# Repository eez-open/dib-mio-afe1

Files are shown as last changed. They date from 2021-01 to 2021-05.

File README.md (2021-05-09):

The [EEZ DIB](https://github.com/eez-open/modular-psu) 4-channel Hi-voltage/Hi-current AFE for [MIO168](https://github.com/eez-open/dib-mio168) module.

### Feature list
* [ADS131E04](https://www.ti.com/product/ADS131E04) 24-bit 4-channel simultaneous sampling ADC with SPI
* 5½ digit effective resolution
* 2 x Hi-voltage channels featuring software selectable 3 measurement ranges (±2.4 V, ±12 V, ±240 V), and one current range (±240 mA)
* 2 x Hi-current channels featuring software selectable 3 measurement ranes (±24 mA, ±1 A, ±10 A) and 2 voltage ranges (±2.4 V, ±12 V)
* Latching relays for lower continous power consumption
* On-board ±2.5 V low noise LDOs
* Optional Voltage reference (LTC6655-2.5)
* Active clamps on ADC inputs
* 20 x 5 mm fueses on hi-current channels (AIN3 and AIN4)
* Dimensions: 143 x 68.5 mm, 4-layer PCB

### r1B2 prototype

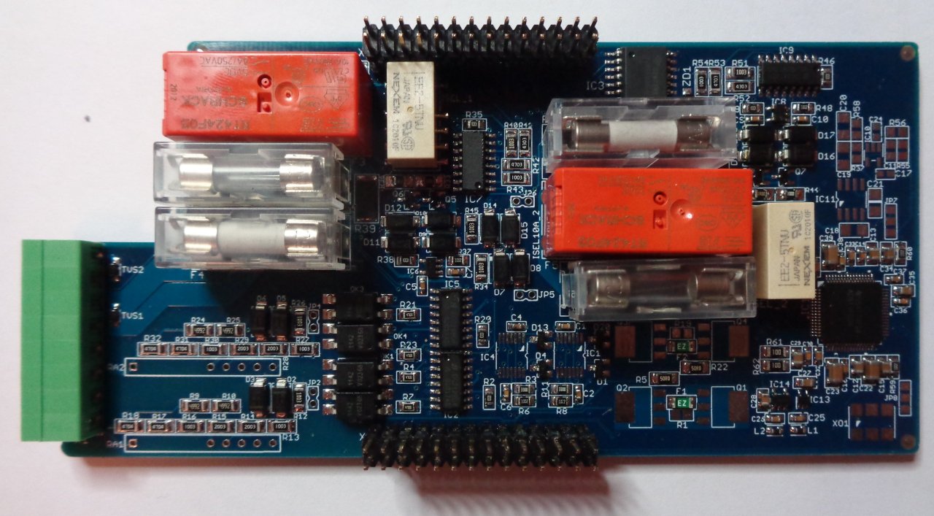
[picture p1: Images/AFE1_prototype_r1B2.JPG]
prototype


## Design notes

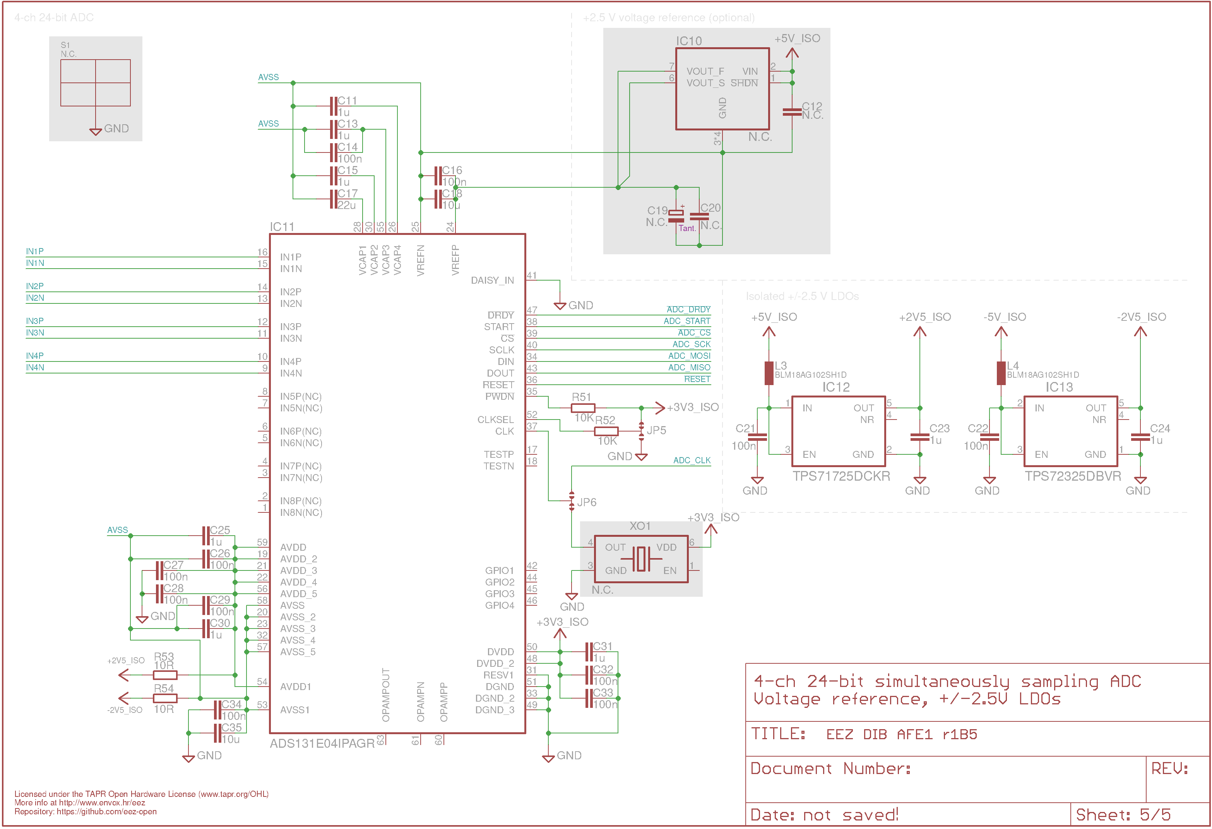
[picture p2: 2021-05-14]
EEZ DIB AFE1 r1B5 Sheet5of5.png

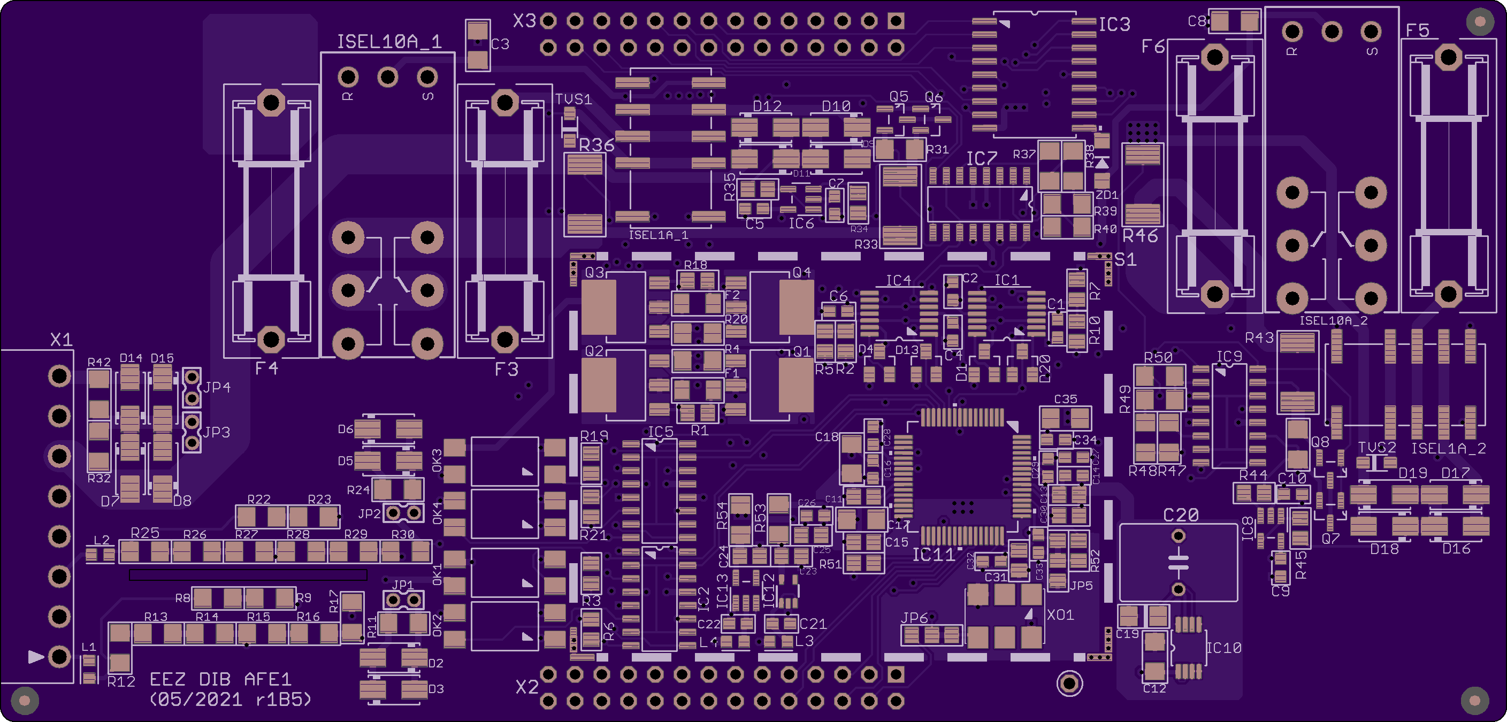
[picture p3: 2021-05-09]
Images/EEZ_DIB_AFE1_PCB_top.png

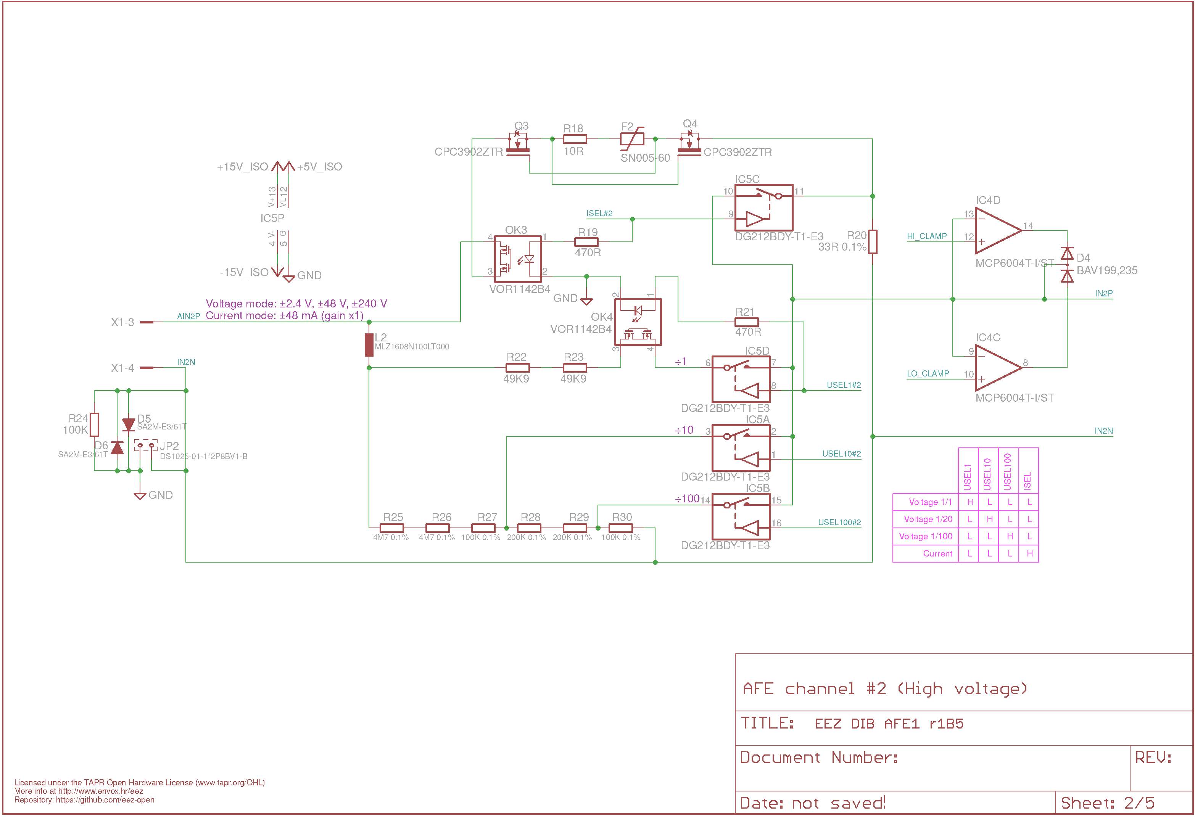
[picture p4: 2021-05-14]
EEZ DIB AFE1 r1B5 Sheet2of5.png

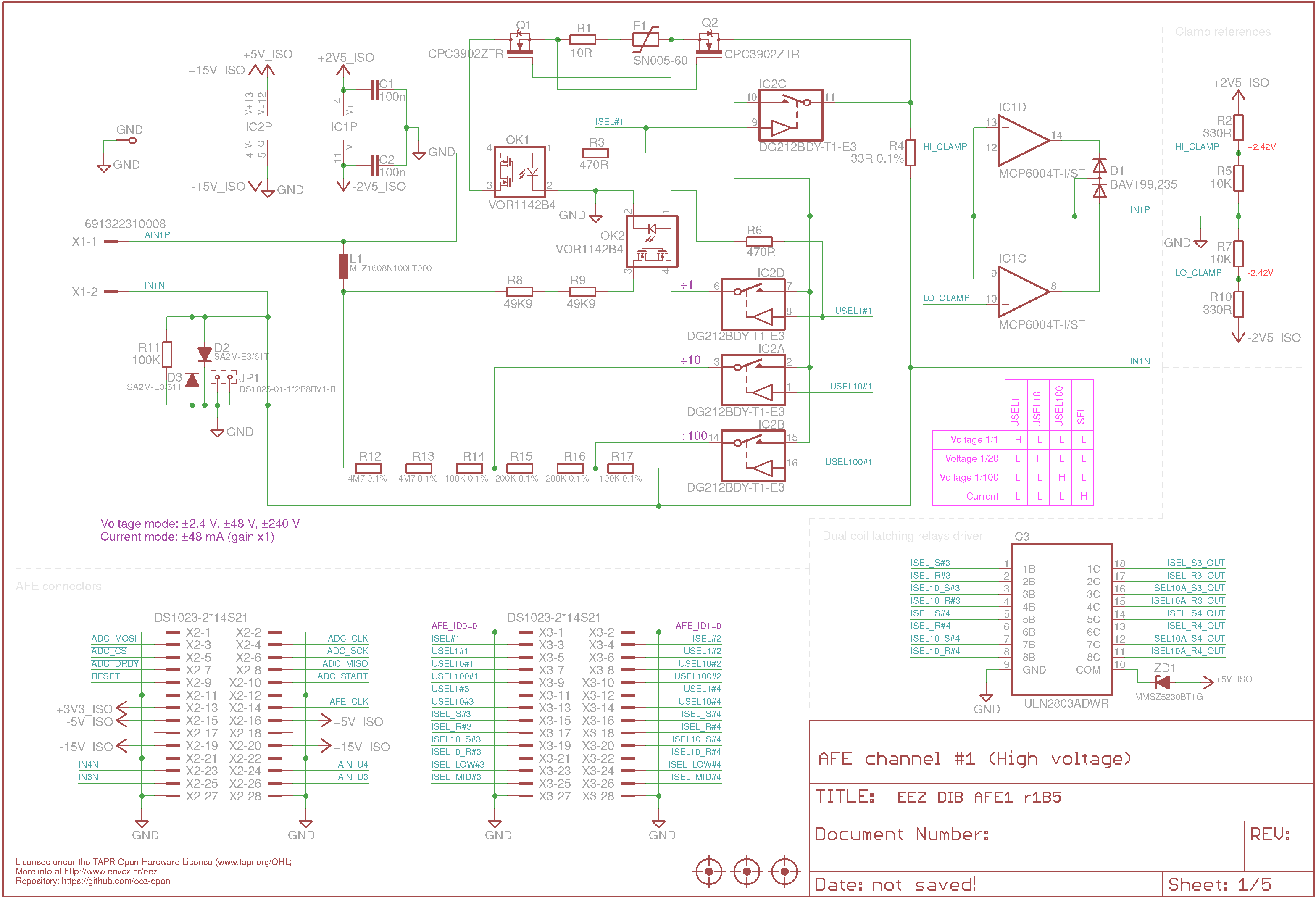
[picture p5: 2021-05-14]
EEZ DIB AFE1 r1B5 Sheet1of5.png

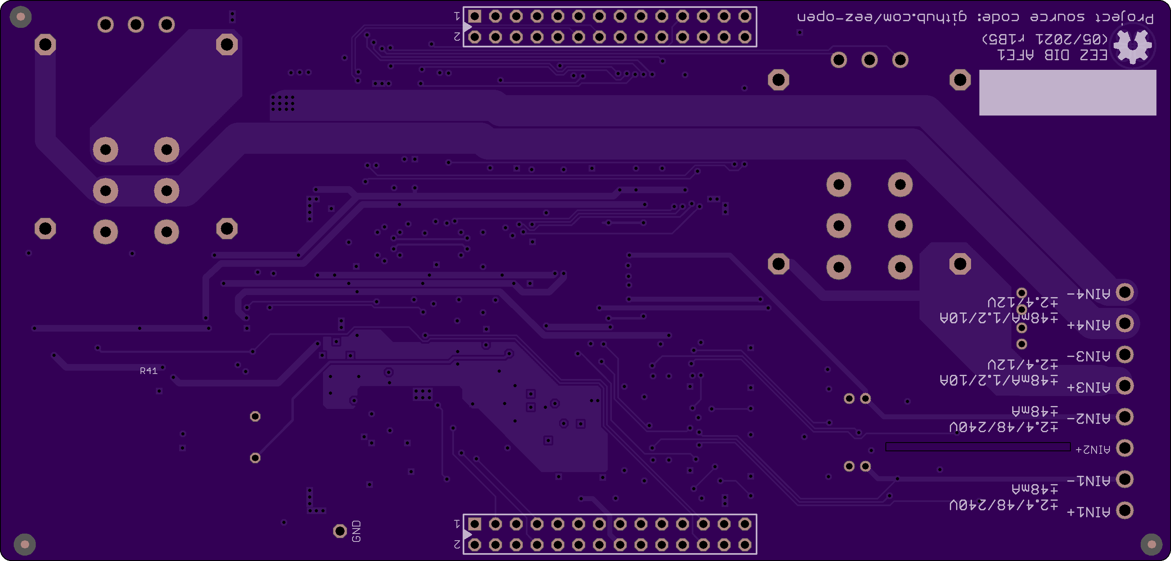
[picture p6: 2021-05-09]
Images/EEZ_DIB_AFE1_PCB_bottom.png

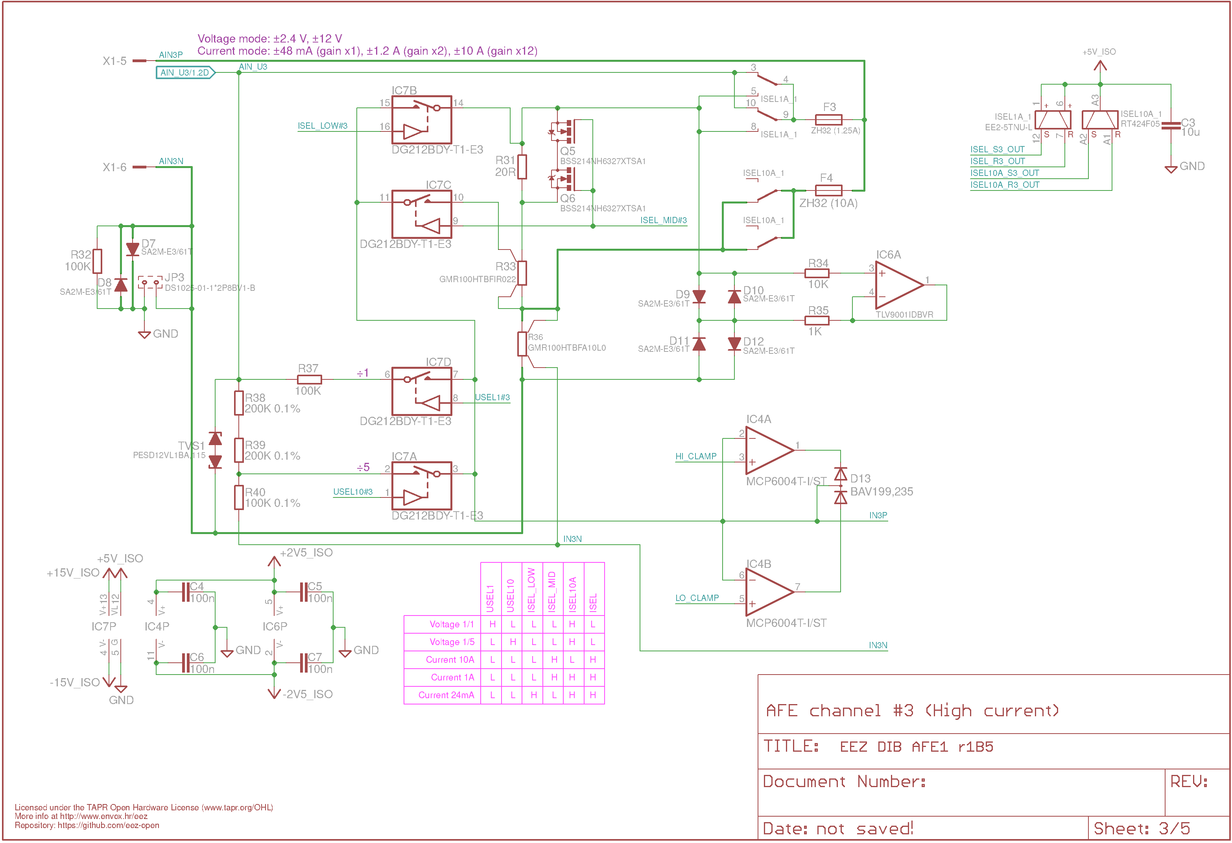
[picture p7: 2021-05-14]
EEZ DIB AFE1 r1B5 Sheet3of5.png

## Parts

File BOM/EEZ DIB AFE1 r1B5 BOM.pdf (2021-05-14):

EEZ DIB AFE1 BOM (r1B5, 2021-05-14)
Project source code at https://github.com/eez-open/modular-psu
Farnell / Element14 # Unit price Qty Part name Package Reference designator Code Part Number MOQ € | Digi-Key Unit price Part Number MOQ € | Mouser Unit price Part Number MOQ €
| | 80-C0603C104M4R
C11, C13, C15, C23, C24, C25, C30, C31 | | 963-TMK212B7105K G-T
| | 603-CC121KKX7R8B B226
MC0603B102K250 CT | | 80-C0603C102J5RA C
| | 810-CGA4J1X7S1C1 06KA
1 | 19 100n | 0603 | 2522597 | 0,073 10 | 490-4774-1-ND | 0,090 100 | 0,085 100
2 | 8 1u | 0805 | 2495193 | 885012207078 | 0,139 | 5 | 1276-1066-1-ND | 0,070 | 10 | 0,050 10
3 | 1 22u | 1206 | C17 | 2320935 | 1,490 | 1 | 1276-3373-1-ND | 0,369 | 10 | 0,777 10
4 | 2 1n | 0603 | C2, C10 | 2627426 | 0,009 10 | 1276-1018-1-ND | 0,026 | 10 | 0,021 10
5 | 4 10u | 1206 | C3, C8, C18, C35 | 3013485 | 0,262 10 | 1276-2872-1-ND | 0,207 | 10 | 0,144 | 1
6 | 4 BAV199,235 | SOT-23 | D1, D4, D13, D20 | 2319137 | BAV199,215 | 0,185 | 5 | 1727-6382-1-ND | 0,145 | 10 | 771-BAV199235 | 0,146 10
7 | 16 SA2M-E3/61T | SMA | 2335163 | SA2M-E3/61T | 0,261 10 | 0,223 | 10 | 78-CSA2M-E3/H | 0,202 10
8 | 1 SN005-60 | 1206 | F1, F2 | 3103210 | 1206L005/60WR | 0,771 | 1 | F8129CT-ND | 0,460 | 1 | | 0,440 | 1
9 | 4 ZH32 | | F3, F4, F5, F6 | - | | | | - | | | -
10 | 2 MCP6004T-I/ST | TSSOP-14 | IC1, IC4 | - | | | | - | | | | 0,373 | 1
11 | 1 ADS131E04IPAGR | TQFP-64 | IC11 | 3123346 | ADS131E04IPAG | 13,450 | 1 | 296-34885-1-ND | 7,560 | 1 | | 8,430 | 1
12 | 1 TPS71725DCKR | SC70-5 | IC12 | 2348004 | TPS71725DCKR . | 0,982 | 1 | 296-21525-1-ND | 0,890 | 1 | | 0,889 | 1
13 | 1 TPS72325DBVR | SOT-23-5 | IC13 | 3007843 | TPS72325DBVR | 2,690 | 1 | 296-39479-1-ND | 2,300 | 1 | | 2,310 | 1
14 | 4 DG212BDY-T1-E3 | SOIC-16 | IC2, IC5, IC7, IC9 | 1469429 | DG212BDY-T1-E3 | 1,820 | 1 | | 1,550 | 1 | | 1,470 | 1
15 | 1 ULN2803ADWR | SOIC-18 | IC3 | 3125103 | ULN2803ADWR | 1,120 | 5 | 296-15777-1-ND | 1,090 | 1 | | 1,090 | 1
16 | 2 | SOT-23-5 | IC6, IC8 | 4974992 | MCP6001T-I/OT | 0,219 | 1 | | 0,200 | 1 | | 0,203 | 1
17 | 2 RT424F05 | | ISEL10A_1, ISEL10A_2 | 3406968 | RT424F05 | 6,450 | 1 | PB2024-ND | 6,370 | 1 | 655-5-1393243-2 | 6,380 | 1
18 | 2 EE2-5TNU-L | | ISEL1A_1, ISEL1A_2 | 2360813 | EE2-5TNU-L | 1,900 | 1 | 399-11021-1-ND | 2,110 | 1 | 80-EE2-5TNU-L | 2,120 | 1
19 | 4 DS1025-01-1*2P8BV1-B | | JP1, JP2, JP3, JP4 | - | | | | - | | | -
20 | 2 MLZ1608N100LT000 | 0603 | L1, L2 | 2564062 | 0,167 10 | 445-6755-1-ND | 0,111 | 10 | 0,086 10
21 | 2 BLM18AG102SH1D | 0603 | L3, L4 | 3471092 | 0,032 10 | 490-7809-1-ND | 0,070 | 10 | 0,051 10
22 | 4 VOR1142B4 | SMD DIP-4 | OK1, OK2, OK3, OK4 | 2889672 | VOR1142B4 | 1,660 | 1 | VOR1142B4-ND | 1,420 | 1 | 78-VOR1142B4 | 1,420 | 1

C1, C2, C4, C5, C6, C7, C9, C10, C14, C16, C21, C22,
C26, C27, C28, C29, C32,
C33, C34

C0603C104K4RAC
7081

MC1210X226K250
CT

CL21B106KOQNN
NE

D2, D3, D5, D6, D7, D8, D9, D10, D11, D12, D14, D15,
D16, D17, D18, D19

CSA2M-E3/ IGICT-ND

| 576-1206L005/60WR

THT; 20x5mm fuse holder
| | 579-MCP6004T-I/ST
| | 595-ADS131E04IPAG R
| | 595-TPS71725DCKR
| | 595-TPS72325DBVR
| DG212BDY-T1-E3CT-ND | 781-DG212BDY-T1-E3
| | 595-ULN2803ADWR
MCP6001T-I/OT or TLV9001IDBVR | MCP6001T-I/ OTCT-ND | 579-MCP6001T-E/OT

THT; DPDT Latching relay
DPDT Latching relay, Gull
Wing Lead
THT; 2- pin header, 2 mm
MLZ1608N100LT0 00 | 810-MLZ1608N100LT 000
| 81-BLM18AG102SH 1D

BLM18AG102SH1
D

# Qty Part name | RS Components | TME | Price calculation for 1 set

Unit price Code Part Number MOQ € | Unit price Code / Part Number MOQ € | THT SMD | | Line Cost €

1 19 100n

2 8 1u

3 1 22u

4 2 1n

5 4 10u

6 4 BAV199,235
7 16 SA2M-E3/61T

8 1 SN005-60

9 4 ZH32
10 2 MCP6004T-I/ST

11 1 ADS131E04IPAGR

12 1 TPS71725DCKR

13 1 TPS72325DBVR

14 4 DG212BDY-T1-E3

15 1 ULN2803ADWR

16 2

17 2 RT424F05
18 2 EE2-5TNU-L

19 4 DS1025-01-1*2P8BV1-B
20 2 MLZ1608N100LT000

21 2 BLM18AG102SH1D

22 4 VOR1142B4

MCP6001T-I/OT or
TLV9001IDBVR
264-4630 | 0,035 25 | CL10B104KA8NNNC | 0,098 100 | 19 | RS | 0,035 € 19 | 0,665
378-665 | 0,038 25 | 0,014 100 | 8 | TME | 0,014 € | 8 | 0,116
766-1182 | 0,343 10 | CL32A226KAJNNNE | 0,158 10 | 1 | TME | 0,158 € | 1 | 0,158
135-6565 | 0,014 100 | 0,010 100 | 2 | Farnell | 0,009 € | 2 | 0,018
184-3969 | 0,233 50 | CL21A106KOQNNNG | 0,034 100 | 4 | TME | 0,034 € | 4 | 0,137
751-3437 BAV199DW-7-F | 0,232 25 | BAV199.215 | 0,035 20 | 4 | TME | 0,035 € | 4 | 0,140
812-9275 SA2M-E3/5AT | 0,116 100 | SA2M-E3/61T | 0,050 50 | 16 | TME | 0,050 € 16 | 0,794
- | SN005-60 | 0,075 10 | 1 | TME | 0,075 € | 1 | 0,075
- | | | ZH32 | 0,228 | 5 | 4 | TME | 0,228 € | 4 | 0,912
- | | | - | | | 2 | Mouser | 0,373 € | 2 | 0,746
817-5705 | 6,050 | 1 | - | | | 1 | RS | 6,050 € | 1 | 6,050
- | | | - | | | 1 | Mouser | 0,889 € | 1 | 0,889
- | | | - | | | 1 | Digikey | 2,300 € | 1 | 2,300
710-4780 | 1,630 | 5 | - | | | 4 | Mouser | 1,470 € | 4 | 5,880
646-6311 ULN2803ADW | 1,336 | 1 | ULN2803ADWR | 0,866 | 1 | 1 | TME | 0,866 € | 1 | 0,866
698-9041 MCP6001T-I/OT | 0,230 | 1 | MCP6001T-I/OT | 0,254 | 3 | 2 | Digikey | 0,203 € | 2 | 0,406
164-7553 RT424F05 | 6,485 | 1 | 5-1393243-2 | 2,500 | 2 | 2 | TME | 2,500 € | 2 | 5,000
870-5517 EE2-5TNU-L | 1,987 | 1 | - | | | 2 | Farnell | 1,900 € | 2 | 3,800
- | ZL303-02P | 0,013 50 | 4 | TME | 0,013 € | 4 | 0,051
- | | | - | | | 2 | Mouser | 0,086 € | 2 | 0,172
839-0803 | 0,025 100 | BLM18AG102SH1D | 0,016 50 | 2 | TME | 0,016 € | 2 | 0,031
180-7266 VOR1142B4 | 1,416 | 5 | - | | | 4 | RS | 1,416 € | 4 | 5,664

Best
Supplier

Lowest
unit price
€

Order
Qty

C0603C104K4R
ACTU

08052R104K8B
B

VJ0805Y105KXXTW1
BC

CL32A226KAJN
NNE

06031C102KAZ
2A

VJ0603Y102KXACW1
BC

EMK212BB7106
MG-T

ADS131E04IPA
G

DG212BDY-T1-
E3

BLM18AG102S
H1D

# Qty Part name Package Reference designator Code Part Number MOQ € | Part Number Unit price MOQ € | Part Number Unit price MOQ Unit price €

| | 849-CPC3902ZTR
BSS214NH6327XT SA1 | BSS214NH6327 XTSA1CT-ND | 726-BSS214NH6327
| 2019-RK73H2ATTD10 R0FCT-ND | 652-CR0805FX-10R0ELF
R11, R24, R32, R37, R42, MCWR08X1003FT R47 L | RMCF0805FT10 0KCT-ND | 71-CRCW0805100K FKEAC
| | 754-RG3216P-4704B-T1
R14, R17, R27, R30, R40, R50 | RG32P100KBCT -ND | 754-RG3216P-1003-BT5
| RG32P200KBCT -ND | 754-RG3216P-2003-BT5
MCWR08X3300FT L | | 279-CRGCQ0805F33 0R
| 311-470CRCT-ND | 71-CRCW0805470R FKEB
1206, low TCR (max. ±25ppm/°C) | | 652-CRT1206BY20R 0ELF
| | 755-GMR100HTBFIR 022
| RC0805FR-071KL | 603-RC0805FR-071KL
| | 755-GMR100HTBFA1 0L0
1206, low TCR (max. ±25ppm/°C) | 13-RT1206BRD0733 RLCT-ND | 603-RT1206BRD0733 RL
| ND | 603-RC0805FR-0710KL
CR1206-FX-4992ELF | RNCP1206FTD4 9K9CT-ND | 791-MR12X4992FTL
| | 771-PESD12VL1BA-T/R
THT, 8-pin 3.81mm terminal block header, male pins | | 710-691322310008
23 | 4 CPC3902ZTR | SOT-223 | Q1, Q2, Q3, Q4 | - | CLA4156-1-ND | 0,570 | 1 | 0,576 | 1
24 | 4 BSS214NH6327XTSA1 SOT-23 | Q5, Q6, Q7, Q8 | 2480650 | 0,408 | 5 | 0,255 | 10 | 0,224 10
25 | 4 10R | 0805 | R1, R18, R53, R54 | 2447556 | 0,009 10 | 0,029 | 10 | 0,012 10
26 | 6 100K | 1206 | 2447551 | 0,010 10 | 0,024 | 10 | 0,040 10
27 | 4 4M7 0.1% | 1206 | R12, R13, R25, R26 | - | 408-2037-1-ND | 0,413 | 10 | 0,356 10
28 | 6 100K 0.1% | 1206 | 1717738 | ERA8AEB101V | 0,482 10 | 0,346 | 10 | 0,226 10
29 | 8 200K 0.1% | 1206 | 1841801 | ERA8AEB204V | 0,468 10 | 0,355 | 10 | 0,226 10
30 | 2 330R | 0805 | R2, R10 | 2447638 | 0,007 10 | A106061CT-ND | 0,038 | 10 | 0,036 10
31 | 4 470R | 0805 | R3, R6, R19, R21 | 1099798 | WCR0805-470RFI | 0,019 10 | 0,039 | 10 | 0,041 10
32 | 2 20R | R31, R41 | - | 311-2930-1-ND | 0,202 | 10 | 0,257 10
33 | 2 GMR100HTBFIR022 | R33, R43 | - | 511-1688-1-ND | 1,090 | 10 | 1,250 | 1
34 | 2 1K | 0805 | R35, R45 | 1099800 | WCR0805-1K0FI | 0,019 10 | 0,039 | 10 | 0,015 10
35 | 2 GMR100HTBFA10L0 | R36, R46 | 2808330 | 1,130 | 5 | 511-1686-1-ND | 1,350 | 1 | 1,080 | 1
36 | 2 33R 0.1% | R4, R20 | - | 0,394 | 10 | 0,266 10
37 | 6 10K | 0805 | R5, R7, R34, R44, R51, R52 9237755 | 0,022 10 | 0,039 | 10 | 0,014 10
38 | 4 49K9 | 1206 | R8, R9, R22, R23 | 2908458 | 0,040 10 | 0,068 | 10 | 0,013 10
39 | 2 PESD12VL1BA,115 | SOD-323 | TVS1, TVS2 | 8737363 | 0,365 | 5 | 1727-3808-1-ND | 0,320 | 10 | 0,296 10
40 | 1 691322310008 | X1 | - | 732-2093-ND | 1,390 | 1 | 1,400 | 1
41 | 2 P125-2214A0BS230A1 | X2, X3 | - | - | -

MCWR08X10R0FT
L

R15, R16, R28, R29, R38,
R39, R48, R49

2512, low TCR (max.
±25ppm/°C)

2512, low TCR (max.
±25ppm/°C)

GMR100HTBFA10
L0
RC0805FR-0710KL | 311-10.0KCRCT-

PESD12VL1BA,11
5

THT; 28-pin 0.1” board-toboard (Producer: DONG
GUAN YLIES PRECISE
CONNECTOR CO.,LTD)

# Qty Part name

23 4 CPC3902ZTR

24 4 BSS214NH6327XTSA1

25 4 10R

26 6 100K

27 4 4M7 0.1%

28 6 100K 0.1%

29 8 200K 0.1%

30 2 330R

31 4 470R

32 2 20R

33 2 GMR100HTBFIR022

34 2 1K

35 2 GMR100HTBFA10L0

36 2 33R 0.1%

37 6 10K

38 4 49K9

39 2 PESD12VL1BA,115

40 1 691322310008

41 2 P125-2214A0BS230A1

Code Part Number MOQ € | Code / Part Number Unit price MOQ € | THT SMD | Line Cost € Unit price

Best
Supplier

Lowest
unit price
€

Order
Qty
- | CPC3902ZTR | 0,310 | 5 | 4 | TME | 0,310 € | 4 | 1,240
827-0058 | 0,107 100 | 0,070 10 | 4 | TME | 0,070 € | 4 | 0,280
740-8987 | 0,065 50 | 0805S8J0111T5E | 0,013 100 | 4 | Farnell | 0,009 € | 4 | 0,034
223-0691 CRG0805F100K | 0,028 50 | 0805S8F1003T5E | 0,015 100 | 6 | Farnell | 0,010 € | 6 | 0,058
- | - | 4 | Mouser | 0,356 € | 4 | 1,424
669-6626 ERA8AEB104V | 0,608 | 5 | AR06BTCV1003 | 0,127 10 | 6 | TME | 0,127 € | 6 | 0,759
828-0715 ERA8AEB204V | 0,608 | 5 | AR06BTCV2003 | 0,127 10 | 8 | TME | 0,127 € | 8 | 1,013
223-0354 CRG0805F330R | 0,040 50 | 0805S8F3300T5E | 0,014 100 | 2 | Farnell | 0,007 € | 2 | 0,014
223-0376 CRG0805F470R | 0,021 50 | RC0805FR-07470R | 0,022 100 | 4 | Farnell | 0,019 € | 4 | 0,076
- | - | 2 | Digikey | 0,202 € | 2 | 0,404
- | - | 2 | Digikey | 1,090 € | 2 | 2,180
223-0427 CRG0805F1K0 | 0,017 50 | RC0805FR-071K | 0,022 100 | 2 | Mouser | 0,015 € | 2 | 0,030
- | - | 2 | Mouser | 1,080 € | 2 | 2,160
- | ARG06DTC0330 | 0,029 10 | 2 | TME | 0,029 € | 2 | 0,058
125-1189 CRG0805F10K | 0,002 100 | RC0805FR-0710K | 0,022 100 | 6 | RS | 0,002 € | 6 | 0,012
679-2174 | 0,039 50 | RC1206FR-0749K9 | 0,029 100 | 4 | Mouser | 0,013 € | 4 | 0,052
508-024 | 0,294 20 | PESD12VL1BA.115 | 0,126 | 5 | 2 | TME | 0,126 € | 2 | 0,252
824-6661 691322310008 | 1,470 | 1 | 15EDGRC3.81-08P | 0,662 | 1 | 1 | TME | 0,662 € | 1 | 0,662
- | - | 2 | -

BSS214NH6327
XTSA1

BSS214NH6327XTSA
1
CR0805-FX-10R0ELF

CRCW120649K
9FKEA
PESD12VL1BA,
115

# Qty Part name Package Reference designator Code Part Number MOQ € | Part Number Unit price MOQ € | Part Number Unit price MOQ Unit price €

| MMSZ5230BT1G OSCT-ND | 863-MMSZ5230BT1G
42 | 1 MMSZ5230BT1G | SOD-123 | ZD1 | 1431272 | MMSZ5230BT1G | 0,177 10 | 0,148 | 10 | 0,170 10

Not installed
1 N.C. | 1206 | C12
4 N.C. | 1206 | C19
1 N.C. | THT | C20
1 N.C. | IC10
5 N.C. | R-EU_R0805 | R4, R9, R40, R41, R42
1 N.C. | S1
1 N.C. | XO1

Related parts and accessories
2 ZKSS-10A
2 ZKSS-1.25A
4 JUMPER-2.0/R | JP1, JP2, JP3, JP4 | - | - | -
1 691304100008 | - | 277-12329-ND | 7,410 | 1 | 651-1748037 | 7,440 | 1

Custom made components
1 | JLCPCB.com | -

All prices are net prices (without VAT)

All resistors are 1% 0805 and all capacitors are X7R 0805 if not otherwise specified.
For small quantities, consider ordering specialized chips at store.ti.com for better prices and availability.

8-pin 3.81mm push-in
connector

PCB 4-layer 141.5 x 68.5
mm

Please note that BOM does not contain ordering number for parts on reels or that which includes re-reeling fee. Take also into account that total cost is higher because min. quantity (MOQ) for many parts is larger then what is needed for single unit.

# Qty Part name

42 1 MMSZ5230BT1G

Not installed
1 N.C.
4 N.C.
1 N.C.
1 N.C.
5 N.C.
1 N.C.
1 N.C.

Related parts and accessories 2 ZKSS-10A
2 ZKSS-1.25A
4 JUMPER-2.0/R
1 691304100008

Custom made components
1 PCB 4-layer 141.5 x 68.5 mm
Code Part Number MOQ € | Code / Part Number Unit price MOQ € | THT SMD | Line Cost € Unit price
| MMSZ5230BT1 G

Best
Supplier

Lowest
unit price
€

Order
Qty
545-3033 | 0,173 20 | MMSZ5230BT1G | 0,033 25 | 1 | TME | 0,033 € | 1 | 0,033
13 | 108 | 45,61 €
ZKSS-10A | 0,459 10 | TME | 0,459 € | 2 | 0,918
ZKSS-1.25A | 0,312 10 | TME | 0,312 € | 2 | 0,624
- | JUMPER-2.0/R | 0,044 20 | TME | 0,044 € | 4 | 0,175
185-4361 691304100008 | 8,900 | 1 | Digikey | 7,410 € | 1 | 7,410

9,13 €

JLCPCB | 8,796 € | 1 | 8,796
| | | 8,80 €
| | Total | 63,53 €

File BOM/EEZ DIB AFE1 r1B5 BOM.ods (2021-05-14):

 |  |  |  |  | Farnell / Element14 |  |  |  | Digi-Key |  |  | Mouser |  |  | RS Components |  |  |  | TME |  |  |  |  | Price calculation for 1 set
# | Qty | Part name | Package | Reference designator | Code | Part Number | Unit price € | MOQ | Part Number | Unit price € | MOQ | Part Number | Unit price € | MOQ | Code | Part Number | Unit price € | MOQ | Code / Part Number | Unit price € | MOQ | THT | SMD | Best Supplier | Lowest unit price € | Order Qty | Line Cost €
1 | 19 | 100n | 0603 | C1, C2, C4, C5, C6, C7, C9, C10, C14, C16, C21, C22, C26, C27, C28, C29, C32, C33, C34 | 2522597 | C0603C104K4RAC7081 | 0,073 | 10 | 490-4774-1-ND | 0,090 | 100 | 80-C0603C104M4R | 0,085 | 100 | 264-4630 | C0603C104K4RACTU | 0,035 | 25 | CL10B104KA8NNNC | 0,098 | 100 |  | 19 | RS | 0,035 € | 19 | 0,665
2 | 8 | 1u | 0805 | C11, C13, C15, C23, C24, C25, C30, C31 | 2495193 | 885012207078 | 0,139 | 5 | 1276-1066-1-ND | 0,070 | 10 | 963-TMK212B7105KG-T | 0,050 | 10 | 378-665 | 08052R104K8BB | 0,038 | 25 | VJ0805Y105KXXTW1BC | 0,014 | 100 |  | 8 | TME | 0,014 € | 8 | 0,116
3 | 1 | 22u | 1206 | C17 | 2320935 | MC1210X226K250CT | 1,490 | 1 | 1276-3373-1-ND | 0,369 | 10 | 603-CC121KKX7R8BB226 | 0,777 | 10 | 766-1182 | CL32A226KAJNNNE | 0,343 | 10 | CL32A226KAJNNNE | 0,158 | 10 |  | 1 | TME | 0,158 € | 1 | 0,158
4 | 2 | 1n | 0603 | C2, C10 | 2627426 | MC0603B102K250CT | 0,009 | 10 | 1276-1018-1-ND | 0,026 | 10 | 80-C0603C102J5RAC | 0,021 | 10 | 135-6565 | 06031C102KAZ2A | 0,014 | 100 | VJ0603Y102KXACW1BC | 0,010 | 100 |  | 2 | Farnell | 0,009 € | 2 | 0,018
5 | 4 | 10u | 1206 | C3, C8, C18, C35 | 3013485 | CL21B106KOQNNNE | 0,262 | 10 | 1276-2872-1-ND | 0,207 | 10 | 810-CGA4J1X7S1C106KA | 0,144 | 1 | 184-3969 | EMK212BB7106MG-T | 0,233 | 50 | CL21A106KOQNNNG | 0,034 | 100 |  | 4 | TME | 0,034 € | 4 | 0,137
6 | 4 | BAV199,235 | SOT-23 | D1, D4, D13, D20 | 2319137 | BAV199,215 | 0,185 | 5 | 1727-6382-1-ND | 0,145 | 10 | 771-BAV199235 | 0,146 | 10 | 751-3437 | BAV199DW-7-F | 0,232 | 25 | BAV199.215 | 0,035 | 20 |  | 4 | TME | 0,035 € | 4 | 0,140
7 | 16 | SA2M-E3/61T | SMA | D2, D3, D5, D6, D7, D8, D9, D10, D11, D12, D14, D15, D16, D17, D18, D19 | 2335163 | SA2M-E3/61T | 0,261 | 10 | CSA2M-E3/IGICT-ND | 0,223 | 10 | 78-CSA2M-E3/H | 0,202 | 10 | 812-9275 | SA2M-E3/5AT | 0,116 | 100 | SA2M-E3/61T | 0,050 | 50 |  | 16 | TME | 0,050 € | 16 | 0,794
8 | 1 | SN005-60 | 1206 | F1, F2 | 3103210 | 1206L005/60WR | 0,771 | 1 | F8129CT-ND | 0,460 | 1 | 576-1206L005/60WR | 0,440 | 1 | - |  |  |  | SN005-60 | 0,075 | 10 |  | 1 | TME | 0,075 € | 1 | 0,075
9 | 4 | ZH32 | THT; 20x5mm fuse holder | F3, F4, F5, F6 | - |  |  |  | - |  |  | - |  |  | - |  |  |  | ZH32 | 0,228 | 5 | 4 |  | TME | 0,228 € | 4 | 0,912
10 | 2 | MCP6004T-I/ST | TSSOP-14 | IC1, IC4 | - |  |  |  | - |  |  | 579-MCP6004T-I/ST | 0,373 | 1 | - |  |  |  | - |  |  |  | 2 | Mouser | 0,373 € | 2 | 0,746
11 | 1 | ADS131E04IPAGR | TQFP-64 | IC11 | 3123346 | ADS131E04IPAG | 13,450 | 1 | 296-34885-1-ND | 7,560 | 1 | 595-ADS131E04IPAGR | 8,430 | 1 | 817-5705 | ADS131E04IPAG | 6,050 | 1 | - |  |  |  | 1 | RS | 6,050 € | 1 | 6,050
12 | 1 | TPS71725DCKR | SC70-5 | IC12 | 2348004 | TPS71725DCKR . | 0,982 | 1 | 296-21525-1-ND | 0,890 | 1 | 595-TPS71725DCKR | 0,889 | 1 | - |  |  |  | - |  |  |  | 1 | Mouser | 0,889 € | 1 | 0,889
13 | 1 | TPS72325DBVR | SOT-23-5 | IC13 | 3007843 | TPS72325DBVR | 2,690 | 1 | 296-39479-1-ND | 2,300 | 1 | 595-TPS72325DBVR | 2,310 | 1 | - |  |  |  | - |  |  |  | 1 | Digikey | 2,300 € | 1 | 2,300
14 | 4 | DG212BDY-T1-E3 | SOIC-16 | IC2, IC5, IC7, IC9 | 1469429 | DG212BDY-T1-E3 | 1,820 | 1 | DG212BDY-T1-E3CT-ND | 1,550 | 1 | 781-DG212BDY-T1-E3 | 1,470 | 1 | 710-4780 | DG212BDY-T1-E3 | 1,630 | 5 | - |  |  |  | 4 | Mouser | 1,470 € | 4 | 5,880
15 | 1 | ULN2803ADWR | SOIC-18 | IC3 | 3125103 | ULN2803ADWR | 1,120 | 5 | 296-15777-1-ND | 1,090 | 1 | 595-ULN2803ADWR | 1,090 | 1 | 646-6311 | ULN2803ADW | 1,336 | 1 | ULN2803ADWR | 0,866 | 1 |  | 1 | TME | 0,866 € | 1 | 0,866
16 | 2 | MCP6001T-I/OT or TLV9001IDBVR | SOT-23-5 | IC6, IC8 | 4974992 | MCP6001T-I/OT | 0,219 | 1 | MCP6001T-I/OTCT-ND | 0,200 | 1 | 579-MCP6001T-E/OT | 0,203 | 1 | 698-9041 | MCP6001T-I/OT | 0,230 | 1 | MCP6001T-I/OT | 0,254 | 3 |  | 2 | Digikey | 0,203 € | 2 | 0,406
17 | 2 | RT424F05 | THT; DPDT Latching relay | ISEL10A_1, ISEL10A_2 | 3406968 | RT424F05 | 6,450 | 1 | PB2024-ND | 6,370 | 1 | 655-5-1393243-2 | 6,380 | 1 | 164-7553 | RT424F05 | 6,485 | 1 | 5-1393243-2 | 2,500 | 2 | 2 |  | TME | 2,500 € | 2 | 5,000
18 | 2 | EE2-5TNU-L | DPDT Latching relay, Gull Wing Lead | ISEL1A_1, ISEL1A_2 | 2360813 | EE2-5TNU-L | 1,900 | 1 | 399-11021-1-ND | 2,110 | 1 | 80-EE2-5TNU-L | 2,120 | 1 | 870-5517 | EE2-5TNU-L | 1,987 | 1 | - |  |  |  | 2 | Farnell | 1,900 € | 2 | 3,800
19 | 4 | DS1025-01-1*2P8BV1-B | THT; 2- pin header, 2 mm | JP1, JP2, JP3, JP4 | - |  |  |  | - |  |  | - |  |  | - |  |  |  | ZL303-02P | 0,013 | 50 | 4 |  | TME | 0,013 € | 4 | 0,051
20 | 2 | MLZ1608N100LT000 | 0603 | L1, L2 | 2564062 | MLZ1608N100LT000 | 0,167 | 10 | 445-6755-1-ND | 0,111 | 10 | 810-MLZ1608N100LT000 | 0,086 | 10 | - |  |  |  | - |  |  |  | 2 | Mouser | 0,086 € | 2 | 0,172
21 | 2 | BLM18AG102SH1D | 0603 | L3, L4 | 3471092 | BLM18AG102SH1D | 0,032 | 10 | 490-7809-1-ND | 0,070 | 10 | 81-BLM18AG102SH1D | 0,051 | 10 | 839-0803 | BLM18AG102SH1D | 0,025 | 100 | BLM18AG102SH1D | 0,016 | 50 |  | 2 | TME | 0,016 € | 2 | 0,031
22 | 4 | VOR1142B4 | SMD DIP-4 | OK1, OK2, OK3, OK4 | 2889672 | VOR1142B4 | 1,660 | 1 | VOR1142B4-ND | 1,420 | 1 | 78-VOR1142B4 | 1,420 | 1 | 180-7266 | VOR1142B4 | 1,416 | 5 | - |  |  |  | 4 | RS | 1,416 € | 4 | 5,664
23 | 4 | CPC3902ZTR | SOT-223 | Q1, Q2, Q3, Q4 | - |  |  |  | CLA4156-1-ND | 0,570 | 1 | 849-CPC3902ZTR | 0,576 | 1 | - |  |  |  | CPC3902ZTR | 0,310 | 5 |  | 4 | TME | 0,310 € | 4 | 1,240
24 | 4 | BSS214NH6327XTSA1 | SOT-23 | Q5, Q6, Q7, Q8 | 2480650 | BSS214NH6327XTSA1 | 0,408 | 5 | BSS214NH6327XTSA1CT-ND | 0,255 | 10 | 726-BSS214NH6327 | 0,224 | 10 | 827-0058 | BSS214NH6327XTSA1 | 0,107 | 100 | BSS214NH6327XTSA1 | 0,070 | 10 |  | 4 | TME | 0,070 € | 4 | 0,280
25 | 4 | 10R | 0805 | R1, R18, R53, R54 | 2447556 | MCWR08X10R0FTL | 0,009 | 10 | 2019-RK73H2ATTD10R0FCT-ND | 0,029 | 10 | 652-CR0805FX-10R0ELF | 0,012 | 10 | 740-8987 | CR0805-FX-10R0ELF | 0,065 | 50 | 0805S8J0111T5E | 0,013 | 100 |  | 4 | Farnell | 0,009 € | 4 | 0,034
26 | 6 | 100K | 1206 | R11, R24, R32, R37, R42, R47 | 2447551 | MCWR08X1003FTL | 0,010 | 10 | RMCF0805FT100KCT-ND | 0,024 | 10 | 71-CRCW0805100KFKEAC | 0,040 | 10 | 223-0691 | CRG0805F100K | 0,028 | 50 | 0805S8F1003T5E | 0,015 | 100 |  | 6 | Farnell | 0,010 € | 6 | 0,058
27 | 4 | 4M7 0.1% | 1206 | R12, R13, R25, R26 | - |  |  |  | 408-2037-1-ND | 0,413 | 10 | 754-RG3216P-4704B-T1 | 0,356 | 10 | - |  |  |  | - |  |  |  | 4 | Mouser | 0,356 € | 4 | 1,424
28 | 6 | 100K 0.1% | 1206 | R14, R17, R27, R30, R40, R50 | 1717738 | ERA8AEB101V | 0,482 | 10 | RG32P100KBCT-ND | 0,346 | 10 | 754-RG3216P-1003-BT5 | 0,226 | 10 | 669-6626 | ERA8AEB104V | 0,608 | 5 | AR06BTCV1003 | 0,127 | 10 |  | 6 | TME | 0,127 € | 6 | 0,759
29 | 8 | 200K 0.1% | 1206 | R15, R16, R28, R29, R38, R39, R48, R49 | 1841801 | ERA8AEB204V | 0,468 | 10 | RG32P200KBCT-ND | 0,355 | 10 | 754-RG3216P-2003-BT5 | 0,226 | 10 | 828-0715 | ERA8AEB204V | 0,608 | 5 | AR06BTCV2003 | 0,127 | 10 |  | 8 | TME | 0,127 € | 8 | 1,013
30 | 2 | 330R | 0805 | R2, R10 | 2447638 | MCWR08X3300FTL | 0,007 | 10 | A106061CT-ND | 0,038 | 10 | 279-CRGCQ0805F330R | 0,036 | 10 | 223-0354 | CRG0805F330R | 0,040 | 50 | 0805S8F3300T5E | 0,014 | 100 |  | 2 | Farnell | 0,007 € | 2 | 0,014
31 | 4 | 470R | 0805 | R3, R6, R19, R21 | 1099798 | WCR0805-470RFI | 0,019 | 10 | 311-470CRCT-ND | 0,039 | 10 | 71-CRCW0805470RFKEB | 0,041 | 10 | 223-0376 | CRG0805F470R | 0,021 | 50 | RC0805FR-07470R | 0,022 | 100 |  | 4 | Farnell | 0,019 € | 4 | 0,076
32 | 2 | 20R | 1206, low TCR (max. ±25ppm/°C) | R31, R41 | - |  |  |  | 311-2930-1-ND | 0,202 | 10 | 652-CRT1206BY20R0ELF | 0,257 | 10 | - |  |  |  | - |  |  |  | 2 | Digikey | 0,202 € | 2 | 0,404
33 | 2 | GMR100HTBFIR022 | 2512, low TCR (max. ±25ppm/°C) | R33, R43 | - |  |  |  | 511-1688-1-ND | 1,090 | 10 | 755-GMR100HTBFIR022 | 1,250 | 1 | - |  |  |  | - |  |  |  | 2 | Digikey | 1,090 € | 2 | 2,180
34 | 2 | 1K | 0805 | R35, R45 | 1099800 | WCR0805-1K0FI | 0,019 | 10 | RC0805FR-071KL | 0,039 | 10 | 603-RC0805FR-071KL | 0,015 | 10 | 223-0427 | CRG0805F1K0 | 0,017 | 50 | RC0805FR-071K | 0,022 | 100 |  | 2 | Mouser | 0,015 € | 2 | 0,030
35 | 2 | GMR100HTBFA10L0 | 2512, low TCR (max. ±25ppm/°C) | R36, R46 | 2808330 | GMR100HTBFA10L0 | 1,130 | 5 | 511-1686-1-ND | 1,350 | 1 | 755-GMR100HTBFA10L0 | 1,080 | 1 | - |  |  |  | - |  |  |  | 2 | Mouser | 1,080 € | 2 | 2,160
36 | 2 | 33R 0.1% | 1206, low TCR (max. ±25ppm/°C) | R4, R20 | - |  |  |  | 13-RT1206BRD0733RLCT-ND | 0,394 | 10 | 603-RT1206BRD0733RL | 0,266 | 10 | - |  |  |  | ARG06DTC0330 | 0,029 | 10 |  | 2 | TME | 0,029 € | 2 | 0,058
37 | 6 | 10K | 0805 | R5, R7, R34, R44, R51, R52 | 9237755 | RC0805FR-0710KL | 0,022 | 10 | 311-10.0KCRCT-ND | 0,039 | 10 | 603-RC0805FR-0710KL | 0,014 | 10 | 125-1189 | CRG0805F10K | 0,002 | 100 | RC0805FR-0710K | 0,022 | 100 |  | 6 | RS | 0,002 € | 6 | 0,012
38 | 4 | 49K9 | 1206 | R8, R9, R22, R23 | 2908458 | CR1206-FX-4992ELF | 0,040 | 10 | RNCP1206FTD49K9CT-ND | 0,068 | 10 | 791-MR12X4992FTL | 0,013 | 10 | 679-2174 | CRCW120649K9FKEA | 0,039 | 50 | RC1206FR-0749K9 | 0,029 | 100 |  | 4 | Mouser | 0,013 € | 4 | 0,052
39 | 2 | PESD12VL1BA,115 | SOD-323 | TVS1, TVS2 | 8737363 | PESD12VL1BA,115 | 0,365 | 5 | 1727-3808-1-ND | 0,320 | 10 | 771-PESD12VL1BA-T/R | 0,296 | 10 | 508-024 | PESD12VL1BA,115 | 0,294 | 20 | PESD12VL1BA.115 | 0,126 | 5 |  | 2 | TME | 0,126 € | 2 | 0,252
40 | 1 | 691322310008 | THT, 8-pin 3.81mm terminal block header, male pins | X1 | - |  |  |  | 732-2093-ND | 1,390 | 1 | 710-691322310008 | 1,400 | 1 | 824-6661 | 691322310008 | 1,470 | 1 | 15EDGRC3.81-08P | 0,662 | 1 | 1 |  | TME | 0,662 € | 1 | 0,662
41 | 2 | P125-2214A0BS230A1 | THT; 28-pin 0.1” board-to-board (Producer: DONG GUAN YLIES PRECISE CONNECTOR CO.,LTD) | X2, X3 | - |  |  |  | - |  |  | - |  |  | - |  |  |  | - |  |  | 2 |  |  |  |  | -
42 | 1 | MMSZ5230BT1G | SOD-123 | ZD1 | 1431272 | MMSZ5230BT1G | 0,177 | 10 | MMSZ5230BT1GOSCT-ND | 0,148 | 10 | 863-MMSZ5230BT1G | 0,170 | 10 | 545-3033 | MMSZ5230BT1G | 0,173 | 20 | MMSZ5230BT1G | 0,033 | 25 |  | 1 | TME | 0,033 € | 1 | 0,033
 |  |  |  |  |  |  |  |  |  |  |  |  |  |  |  |  |  |  |  |  |  | 13 | 108 |  |  |  | 45,61 €
 |  | Not installed
 | 1 | N.C. | 1206 | C12
 | 4 | N.C. | 1206 | C19
 | 1 | N.C. | THT | C20
 | 1 | N.C. |  | IC10
 | 5 | N.C. | R-EU_R0805 | R4, R9, R40, R41, R42
 | 1 | N.C. |  | S1
 | 1 | N.C. |  | XO1
 |  | Related parts and accessories
 | 2 | ZKSS-10A |  |  |  |  |  |  |  |  |  |  |  |  |  |  |  |  | ZKSS-10A | 0,459 | 10 |  |  | TME | 0,459 € | 2 | 0,918
 | 2 | ZKSS-1.25A |  |  |  |  |  |  |  |  |  |  |  |  |  |  |  |  | ZKSS-1.25A | 0,312 | 10 |  |  | TME | 0,312 € | 2 | 0,624
 | 4 | JUMPER-2.0/R |  | JP1, JP2, JP3, JP4 | - |  |  |  | - |  |  | - |  |  | - |  |  |  | JUMPER-2.0/R | 0,044 | 20 |  |  | TME | 0,044 € | 4 | 0,175
 | 1 | 691304100008 | 8-pin 3.81mm push-in connector |  | - |  |  |  | 277-12329-ND | 7,410 | 1 | 651-1748037 | 7,440 | 1 | 185-4361 | 691304100008 | 8,900 | 1 |  |  |  |  |  | Digikey | 7,410 € | 1 | 7,410
 |  |  |  |  |  |  |  |  |  |  |  |  |  |  |  |  |  |  |  |  |  |  |  |  |  |  | 9,13 €
 |  | Custom made components
 | 1 | PCB 4-layer 141.5 x 68.5 mm | JLCPCB.com | - |  |  |  |  |  |  |  |  |  |  |  |  |  |  |  |  |  |  |  | JLCPCB | 8,796 € | 1 | 8,796
 |  |  |  |  |  |  |  |  |  |  |  |  |  |  |  |  |  |  |  |  |  |  |  |  |  |  | 8,80 €
 |  |  | All prices are net prices (without VAT)
 |  |  |  |  |  |  |  |  |  |  |  |  |  |  |  |  |  |  |  |  |  |  |  |  |  | Total | 63,53 €
 |  |  | Please note that BOM does not contain ordering number for parts on reels or that which includes re-reeling fee. Take also into account that total cost is higher because min. quantity (MOQ) for many parts is larger then what is needed for single unit.
 |  |  | All resistors are 1% 0805 and all capacitors are X7R 0805 if not otherwise specified.
 |  |  | For small quantities, consider ordering specialized chips at store.ti.com for better prices and availability.

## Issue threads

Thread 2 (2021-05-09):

Middle current range Rsense routing error

prasimix, 2021-05-09:
Rsense for middle current range on AIN4 is not probably not properly routed and that generates a huge error that is temperature dependent.

prasimix, 2021-05-09:
Fixed

Closed 2021-05-09.

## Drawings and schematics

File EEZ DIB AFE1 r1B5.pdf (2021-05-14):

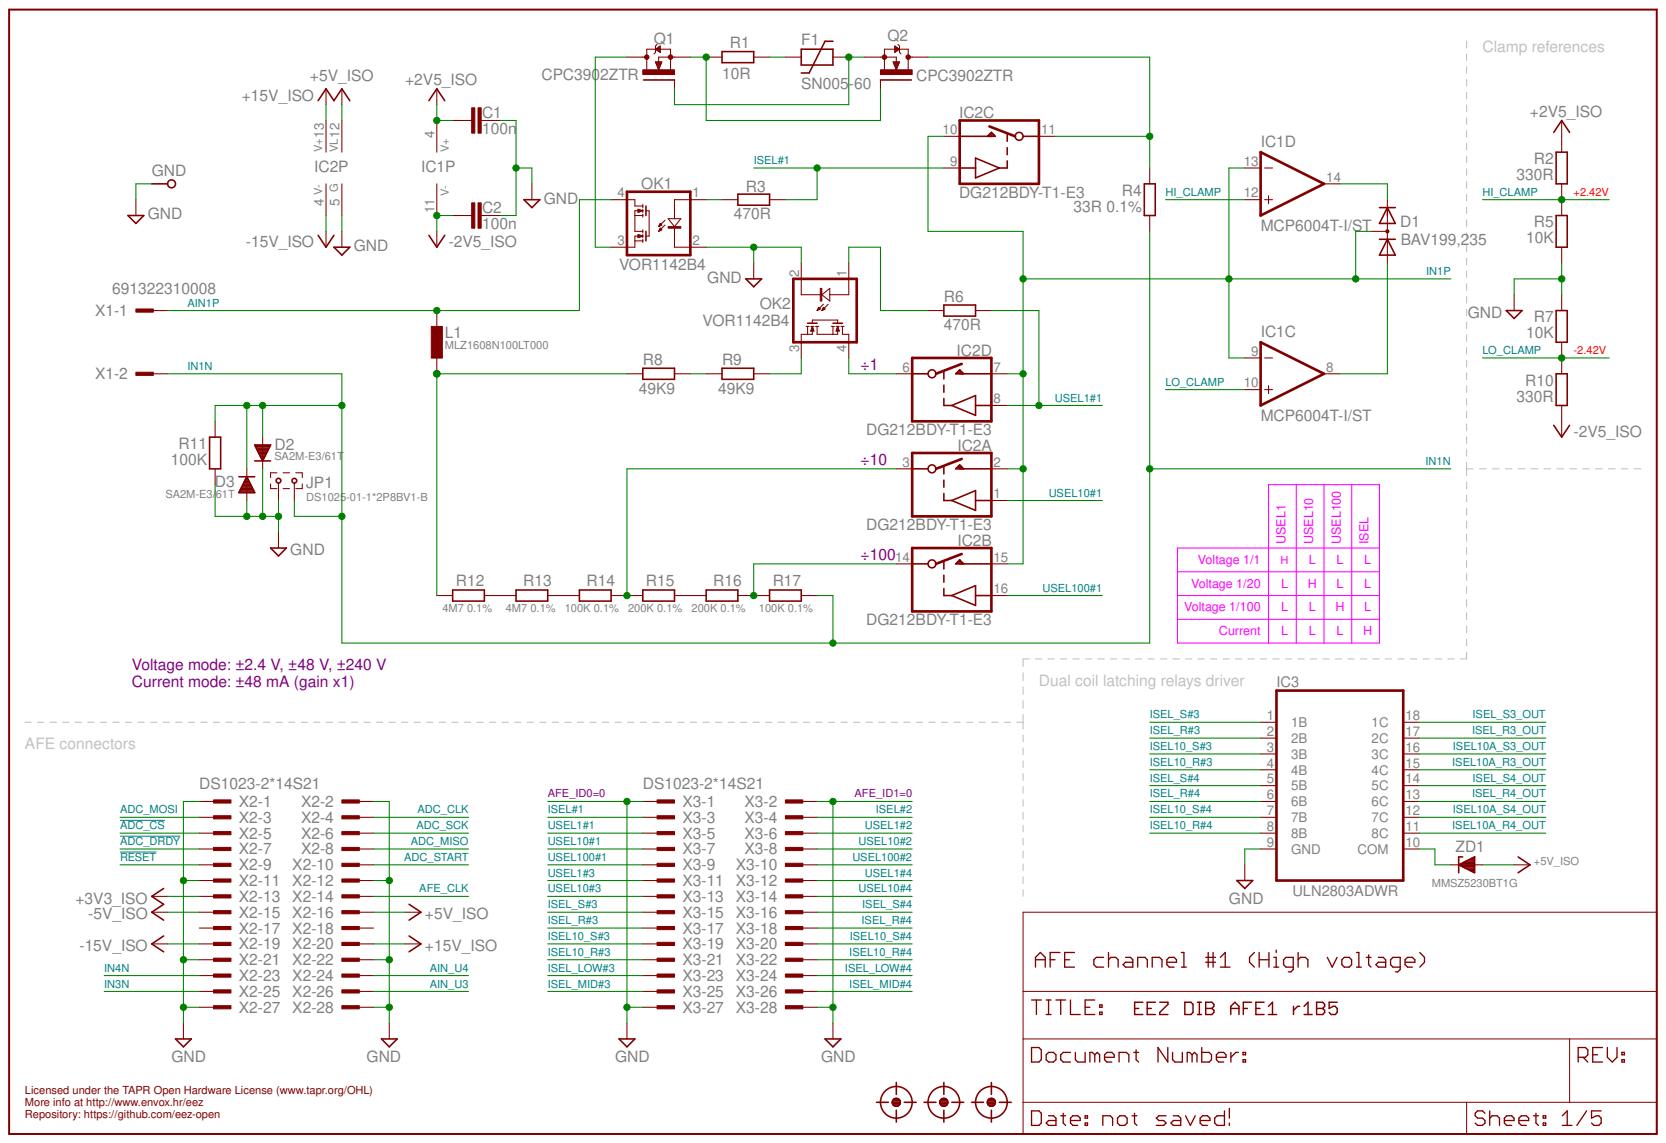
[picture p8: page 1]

L | L | L L H

Voltage mode: ±2.4 V, ±48 V, ±240 V
Current mode: ±48 mA (gain x1)

Dual coil latching relays driver AFE connectors

Licensed under the TAPR Open Hardware License (www.tapr.org/OHL) Repository: https://github.com/eez-open More info at http://www.envox.hr/eez

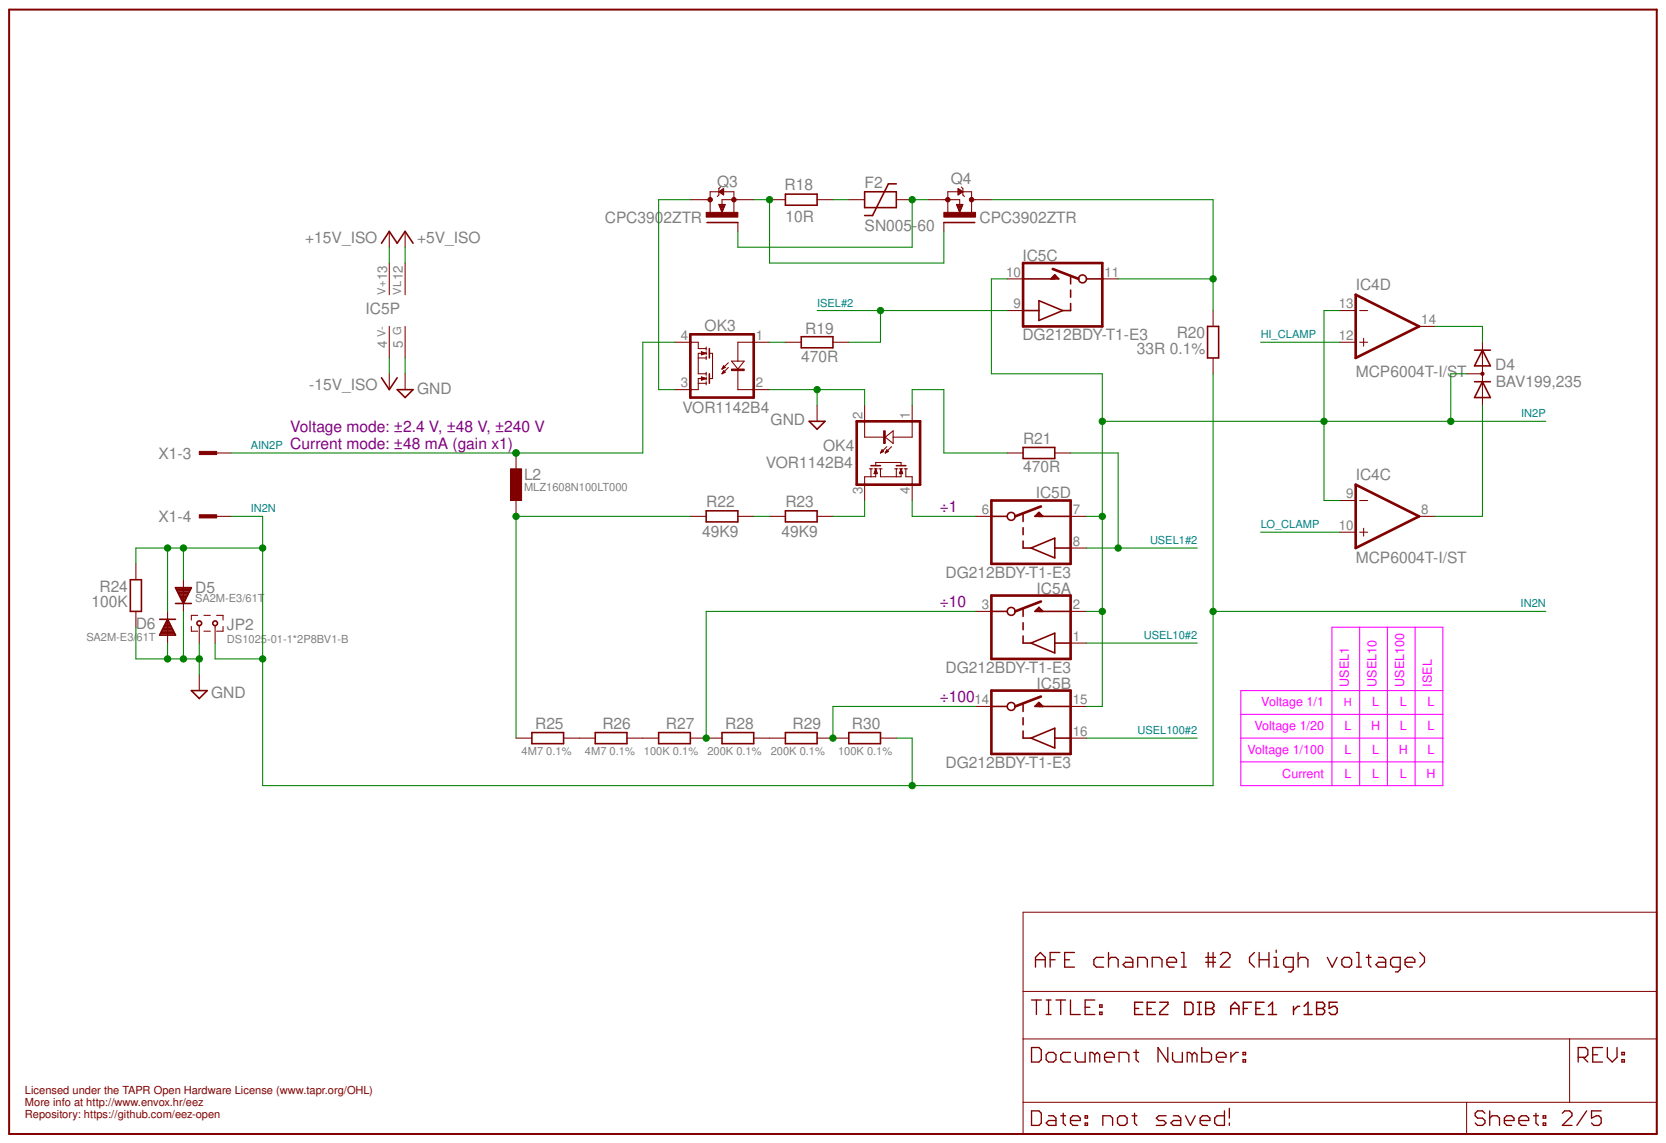
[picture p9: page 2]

Voltage mode: ±2.4 V, ±48 V, ±240 V
Current mode: ±48 mA (gain x1)

L | L | L L H

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

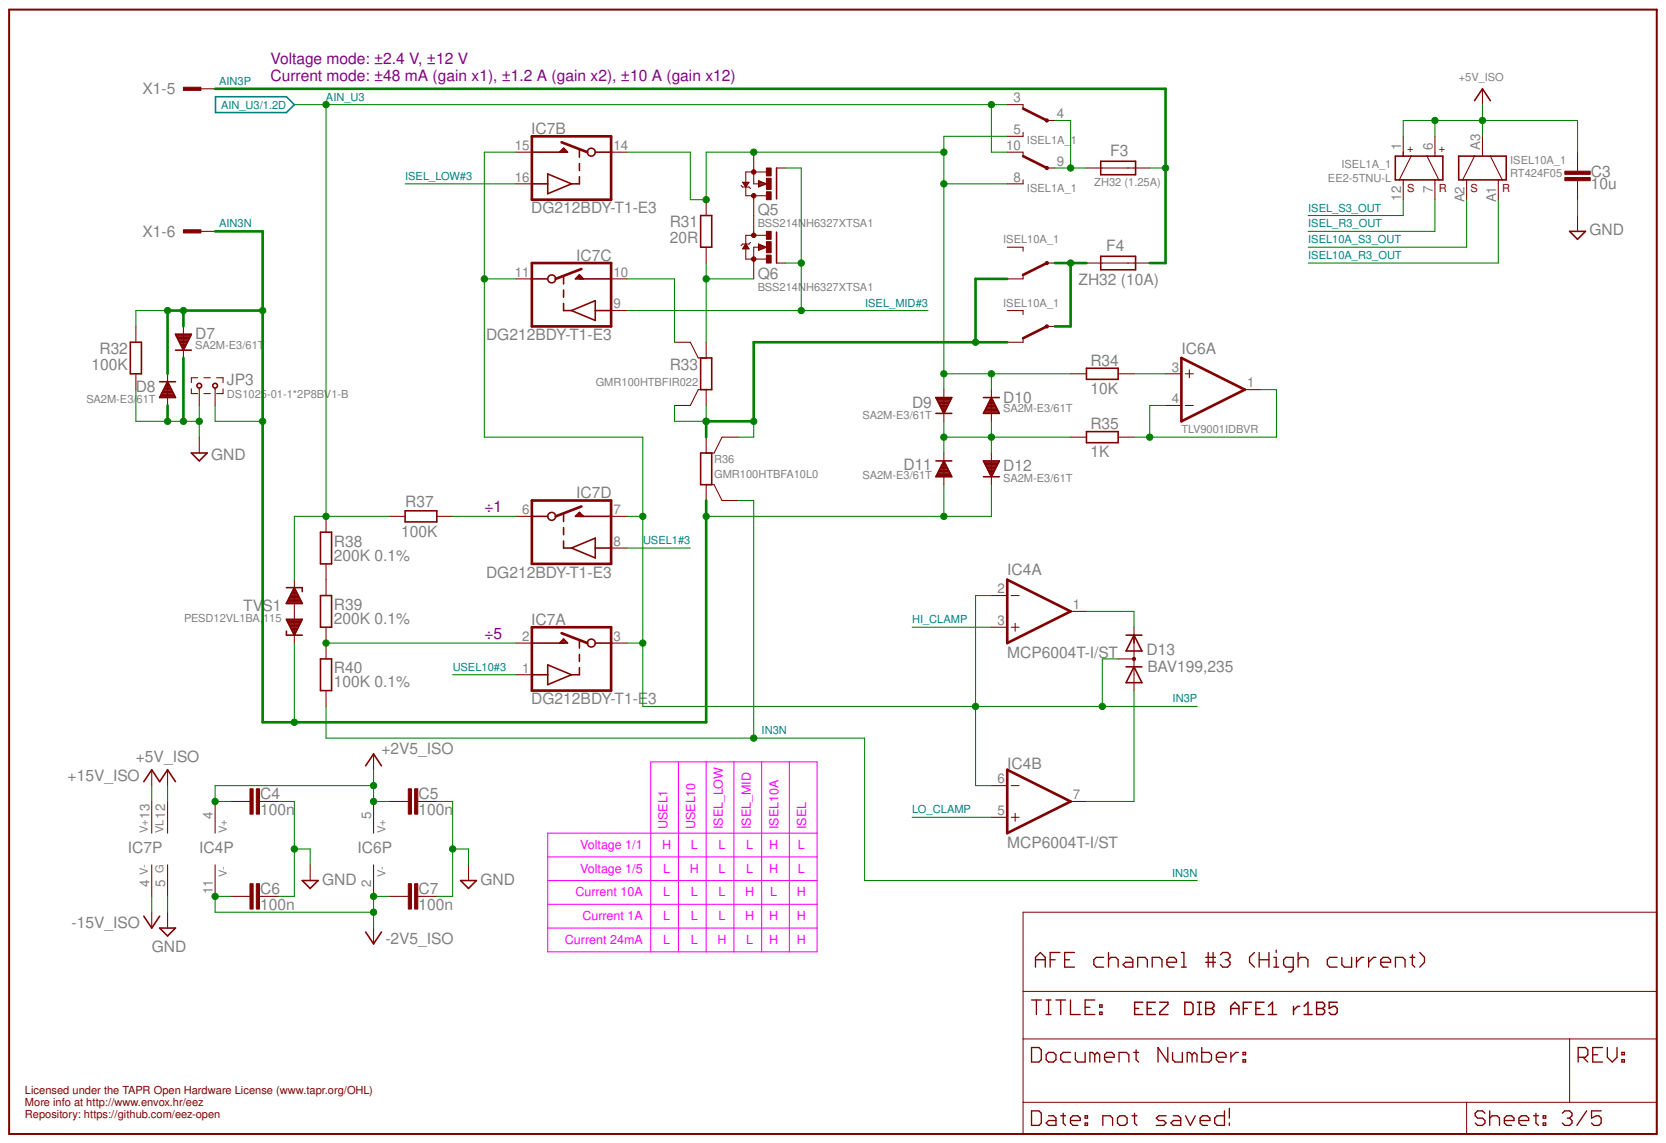
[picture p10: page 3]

Voltage mode: ±2.4 V, ±12 V
Current mode: ±48 mA (gain x1), ±1.2 A (gain x2), ±10 A (gain x12)

Voltage 1/5 Voltage 1/1 Current 10A Current 24mA Current 1A | L | H | L | | LH | L

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

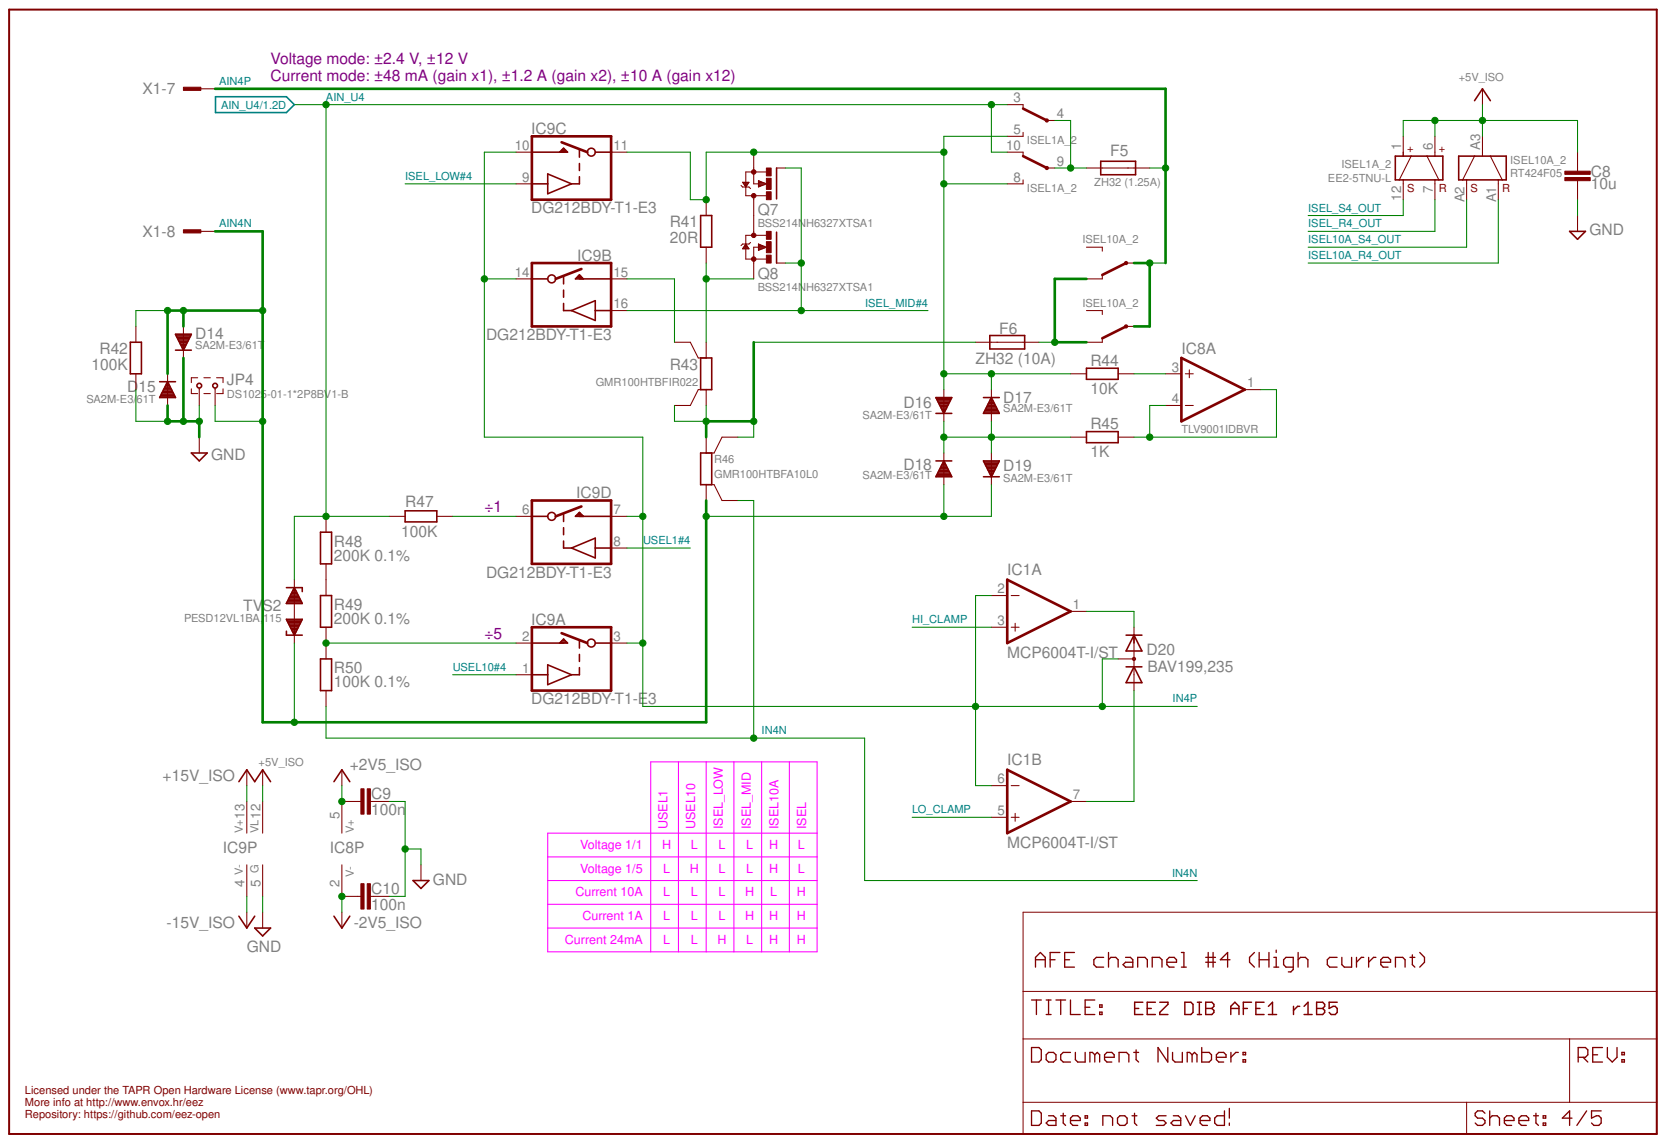
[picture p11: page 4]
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

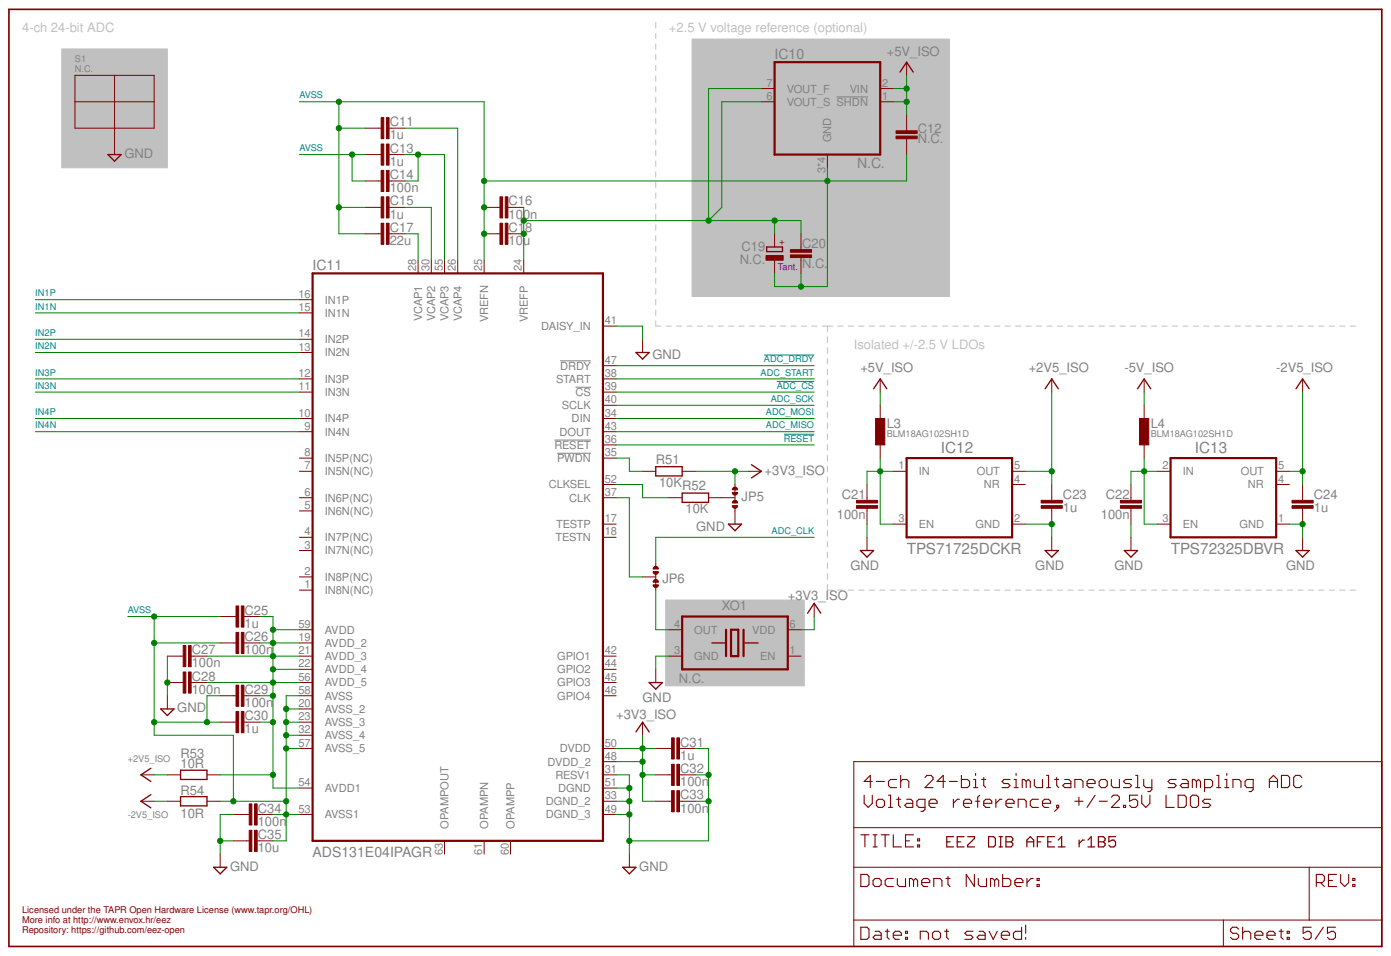
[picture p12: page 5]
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

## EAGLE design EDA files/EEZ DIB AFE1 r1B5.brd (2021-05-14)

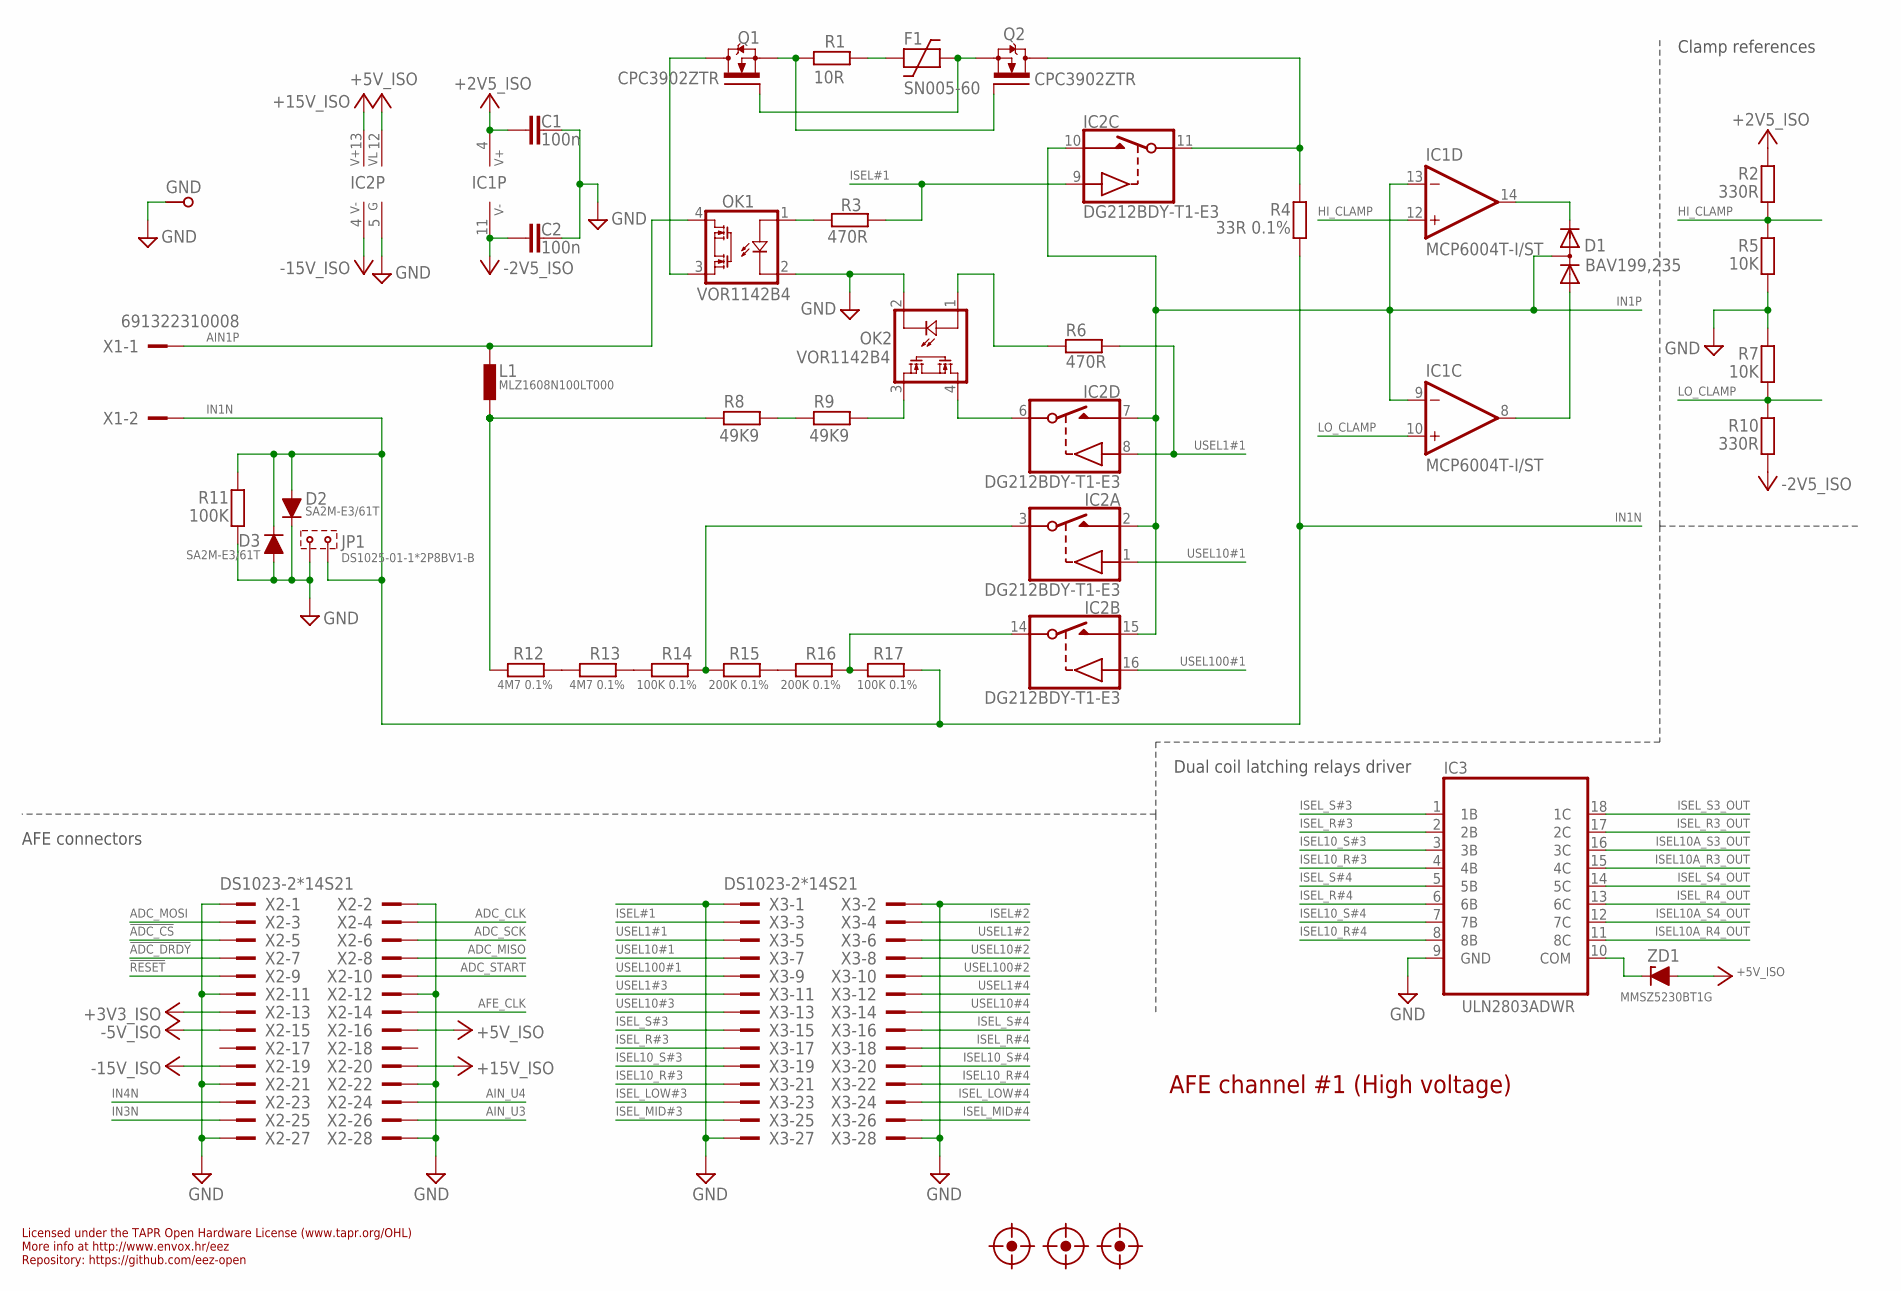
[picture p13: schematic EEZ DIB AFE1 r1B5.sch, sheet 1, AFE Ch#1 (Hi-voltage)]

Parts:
C1, C2: 100n; C0603
D1: BAV199,235; SOT23
D2, D3: SA2M-E3/61T; SMA_NARROW
F1: SN005-60; C1206-HV
FM1, FM2, FM3: FIDUCIAL_2; FIDUCIAL_DUAL
GND: PCB_TEST_TABSHIELD; PCB_SHIELD_TAB
IC1: MCP6004T-I/ST; PW(R-PDSO-G14)
IC2: DG212BDY-T1-E3; SO16
IC3: ULN2803ADWR; DW18_TEX-M
JP1: DS1025-01-1*2P8BV1-B; 2MM-2
L1: MLZ1608N100LT000; BEAD0603
OK1, OK2: VOR1142B4; DIL4-SMD
Q1, Q2: CPC3902ZTR; SOT230P700X180-4N
R1: 10R; R0805
R2, R10: 330R; R0805
R3, R6: 470R; R0805
R4: 33R 0.1%; R1206
R5, R7: 10K; R0805
R8, R9: 49K9; R1206
R11: 100K; R1206
R12, R13: 4M7 0.1%; R1206
R14, R17: 100K 0.1%; R1206
R15, R16: 200K 0.1%; R1206
X1: 691322310008
X2, X3: DS1023-2*14S21; TSW-114-07-F-D
ZD1: MMSZ5230BT1G; SOD123

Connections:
!ADC_CS: X2.5; also elsewhere on the board
!ADC_DRDY: X2.7; also elsewhere on the board
!RESET: X2.9; also elsewhere on the board
+2V5_ISO: C1.2, IC1.4 (V+), R2.1; also elsewhere on the board
+3V3_ISO: X2.13; also elsewhere on the board
+5V_ISO: IC2.12 (VL), X2.16, ZD1.A; also elsewhere on the board
+15V_ISO: IC2.13 (V+), X2.20; also elsewhere on the board
-2V5_ISO: C2.2, IC1.11 (V-), R10.2; also elsewhere on the board
-5V_ISO: X2.15; also elsewhere on the board
-15V_ISO: IC2.4 (V-), X2.19; also elsewhere on the board
ADC_CLK: X2.4; also elsewhere on the board
ADC_MISO: X2.8; also elsewhere on the board
ADC_MOSI: X2.3; also elsewhere on the board
ADC_SCK: X2.6; also elsewhere on the board
ADC_START: X2.10; also elsewhere on the board
AFE_CLK: X2.14
AIN1P: L1.P$2 (2), OK1.4 (S1), X1.1
AIN_U3: X2.26; also elsewhere on the board
AIN_U4: X2.24; also elsewhere on the board
CURR#1: IC2.11 (S), Q2.2 (D), Q2.4 (D), R4.2
CURR_IN#1: OK1.3 (S2), Q1.2 (D), Q1.4 (D)
GND: C1.1, C2.1, D2.1 (C), D3.2 (A), GND.1, IC2.5 (GND), IC3.9 (GND), JP1.2, OK1.2 (C), OK2.2 (C), R5.2, R7.1, R11.1, X2.1, X2.2, X2.11, X2.12, X2.21, X2.22, X2.27, X2.28, X3.1, X3.2, X3.27, X3.28; also elsewhere on the board
HI_CLAMP: IC1.12 (+IN), R2.2, R5.1; also elsewhere on the board
IN1N: D2.2 (A), D3.1 (C), JP1.1, R4.1, R11.2, R17.1, X1.2; also elsewhere on the board
IN1P: D1.3 (AC), IC1.9 (-IN), IC1.13 (-IN), IC2.2 (D), IC2.7 (D), IC2.10 (D), IC2.15 (D); also elsewhere on the board
IN3N: X2.25; also elsewhere on the board
IN4N: X2.23; also elsewhere on the board
ISEL10A_R3_OUT: IC3.15 (4C); also elsewhere on the board
ISEL10A_R4_OUT: IC3.11 (8C); also elsewhere on the board
ISEL10A_S3_OUT: IC3.16 (3C); also elsewhere on the board
ISEL10A_S4_OUT: IC3.12 (7C); also elsewhere on the board
ISEL10_R#3: IC3.4 (4B), X3.21
ISEL10_R#4: IC3.8 (8B), X3.22
ISEL10_S#3: IC3.3 (3B), X3.19
ISEL10_S#4: IC3.7 (7B), X3.20
ISEL#1: IC2.9 (IN), R3.2, X3.3
ISEL#2: X3.4; also elsewhere on the board
ISEL_LOW#3: X3.23; also elsewhere on the board
ISEL_LOW#4: X3.24; also elsewhere on the board
ISEL_MID#3: X3.25; also elsewhere on the board
ISEL_MID#4: X3.26; also elsewhere on the board
ISEL_R3_OUT: IC3.17 (2C); also elsewhere on the board
ISEL_R4_OUT: IC3.13 (6C); also elsewhere on the board
ISEL_R#3: IC3.2 (2B), X3.17
ISEL_R#4: IC3.6 (6B), X3.18
ISEL_S3_OUT: IC3.18 (1C); also elsewhere on the board
ISEL_S4_OUT: IC3.14 (5C); also elsewhere on the board
ISEL_S#3: IC3.1 (1B), X3.15
ISEL_S#4: IC3.5 (5B), X3.16
LO_CLAMP: IC1.10 (+IN), R7.2, R10.1; also elsewhere on the board
unnamed: L1.P$1 (1), R8.2, R12.2
unnamed: OK2.1 (A), R6.2
unnamed: F1.2, Q1.1 (G), Q2.3 (S)
unnamed: Q1.3 (S), Q2.1 (G), R1.2
unnamed: R15.1, R16.2
unnamed: IC3.10 (COM), ZD1.C
unnamed: OK1.1 (A), R3.1
unnamed: R13.1, R14.2
unnamed: R12.1, R13.2
unnamed: IC2.14 (S), R16.1, R17.2
unnamed: IC2.6 (S), OK2.4 (S1)
unnamed: OK2.3 (S2), R9.1
unnamed: F1.1, R1.1
unnamed: D1.2 (C), IC1.14 (OUT)
unnamed: D1.1 (A), IC1.8 (OUT)
unnamed: R8.1, R9.2
unnamed: IC2.3 (S), R14.1, R15.2
USEL1#1: IC2.8 (IN), R6.1, X3.5
USEL1#2: X3.6; also elsewhere on the board
USEL1#3: X3.11; also elsewhere on the board
USEL1#4: X3.12; also elsewhere on the board
USEL10#1: IC2.1 (IN), X3.7
USEL10#2: X3.8; also elsewhere on the board
USEL10#3: X3.13; also elsewhere on the board
USEL10#4: X3.14; also elsewhere on the board
USEL100#1: IC2.16 (IN), X3.9
USEL100#2: X3.10; also elsewhere on the board

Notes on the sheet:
Licensed under the TAPR Open Hardware License (www.tapr.org/OHL)
Repository: https://github.com/eez-open
More info at http://www.envox.hr/eez
AFE channel #1 (High voltage)
Dual coil latching relays driver
AFE connectors
Clamp references

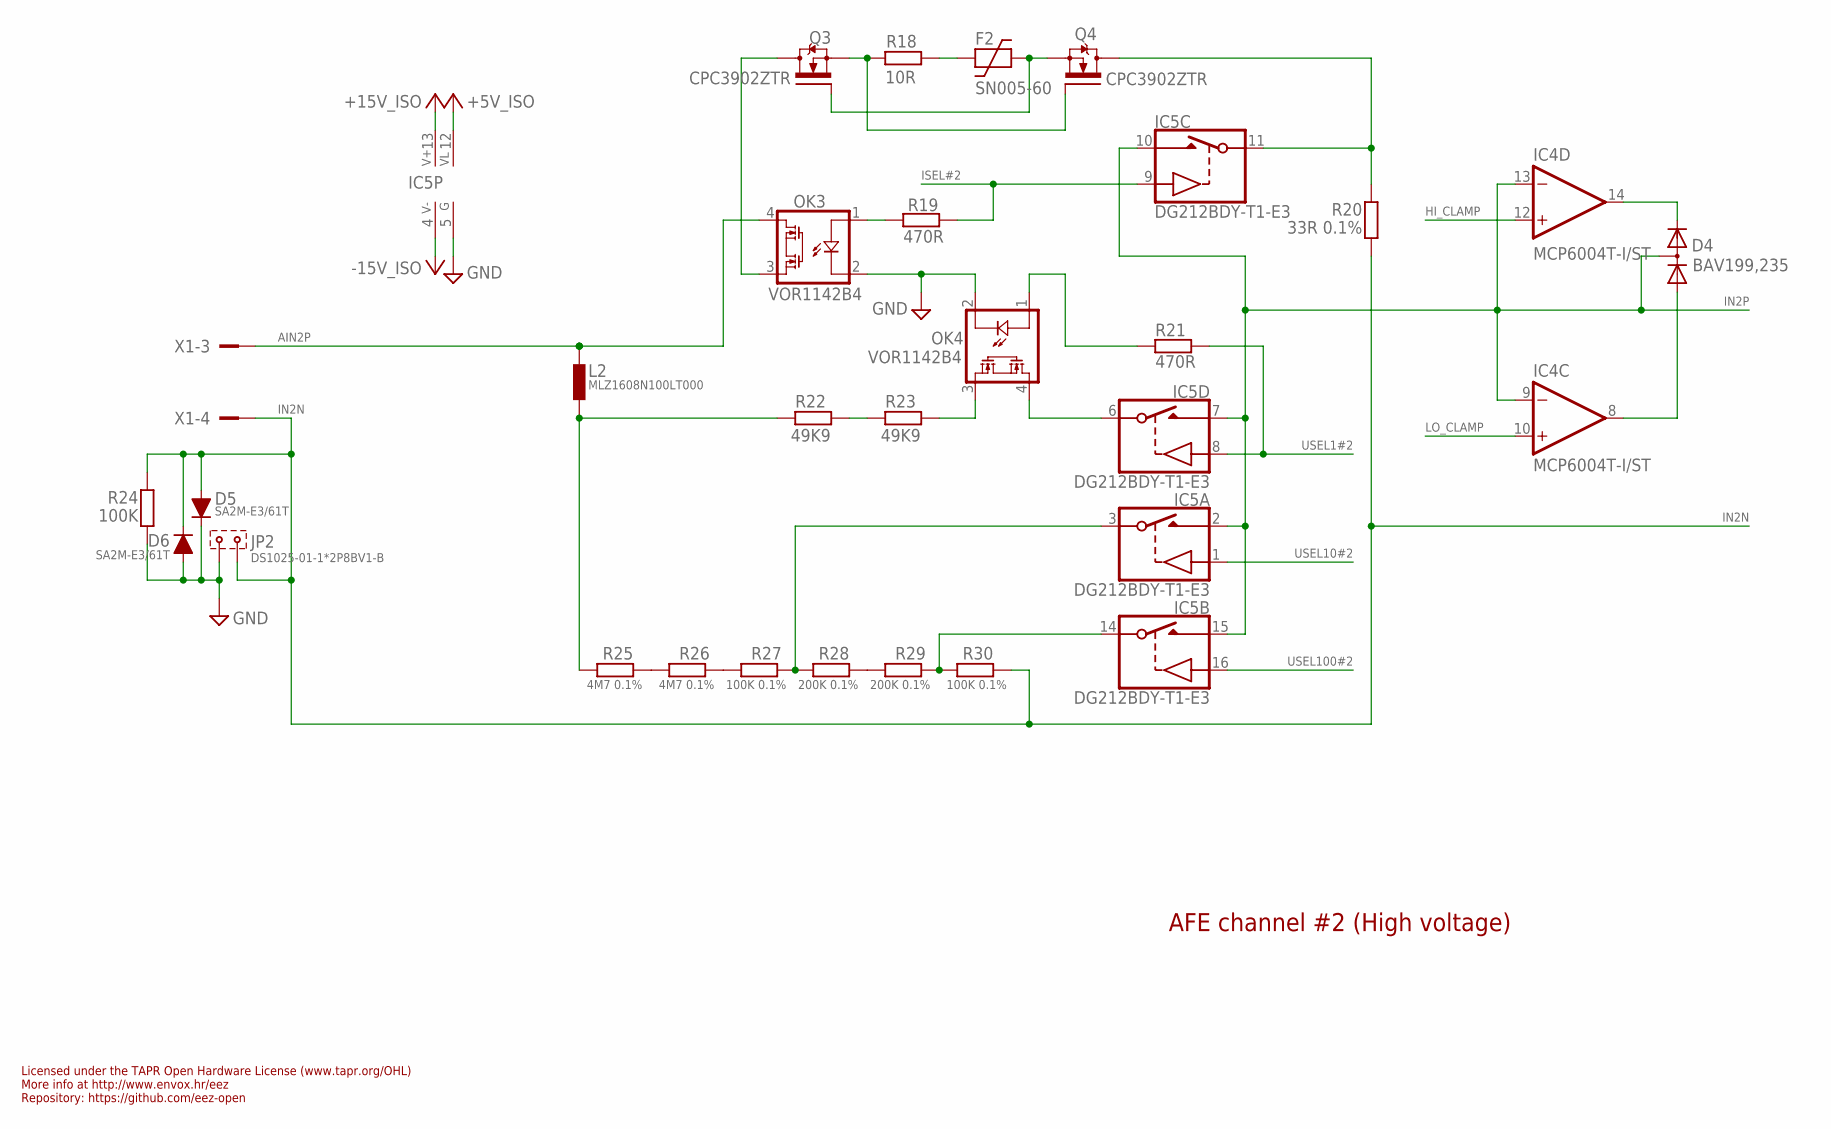
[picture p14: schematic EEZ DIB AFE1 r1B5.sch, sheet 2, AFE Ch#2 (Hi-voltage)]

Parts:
D4: BAV199,235; SOT23
D5, D6: SA2M-E3/61T; SMA_NARROW
F2: SN005-60; C1206-HV
IC4: MCP6004T-I/ST; PW(R-PDSO-G14)
IC5: DG212BDY-T1-E3; SO16
JP2: DS1025-01-1*2P8BV1-B; 2MM-2
L2: MLZ1608N100LT000; BEAD0603
OK3, OK4: VOR1142B4; DIL4-SMD
Q3, Q4: CPC3902ZTR; SOT230P700X180-4N
R18: 10R; R0805
R19, R21: 470R; R0805
R20: 33R 0.1%; R1206
R22, R23: 49K9; R1206
R24: 100K; R1206
R25, R26: 4M7 0.1%; R1206
R27, R30: 100K 0.1%; R1206
R28, R29: 200K 0.1%; R1206
X1: 691322310008

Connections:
+5V_ISO: IC5.12 (VL); also elsewhere on the board
+15V_ISO: IC5.13 (V+); also elsewhere on the board
-15V_ISO: IC5.4 (V-); also elsewhere on the board
AIN2P: L2.P$2 (2), OK3.4 (S1), X1.3
CURR#2: IC5.11 (S), Q4.2 (D), Q4.4 (D), R20.2
CURR_IN#2: OK3.3 (S2), Q3.2 (D), Q3.4 (D)
GND: D5.1 (C), D6.2 (A), IC5.5 (GND), JP2.2, OK3.2 (C), OK4.2 (C), R24.1; also elsewhere on the board
HI_CLAMP: IC4.12 (+IN); also elsewhere on the board
IN2N: D5.2 (A), D6.1 (C), JP2.1, R20.1, R24.2, R30.1, X1.4; also elsewhere on the board
IN2P: D4.3 (AC), IC4.9 (-IN), IC4.13 (-IN), IC5.2 (D), IC5.7 (D), IC5.10 (D), IC5.15 (D); also elsewhere on the board
ISEL#2: IC5.9 (IN), R19.2; also elsewhere on the board
LO_CLAMP: IC4.10 (+IN); also elsewhere on the board
unnamed: L2.P$1 (1), R22.2, R25.2
unnamed: IC5.14 (S), R29.1, R30.2
unnamed: IC5.6 (S), OK4.4 (S1)
unnamed: OK4.3 (S2), R23.1
unnamed: D4.2 (C), IC4.14 (OUT)
unnamed: D4.1 (A), IC4.8 (OUT)
unnamed: R22.1, R23.2
unnamed: IC5.3 (S), R27.1, R28.2
unnamed: R28.1, R29.2
unnamed: R26.1, R27.2
unnamed: R25.1, R26.2
unnamed: OK3.1 (A), R19.1
unnamed: OK4.1 (A), R21.2
unnamed: F2.2, Q3.1 (G), Q4.3 (S)
unnamed: Q3.3 (S), Q4.1 (G), R18.2
unnamed: F2.1, R18.1
USEL1#2: IC5.8 (IN), R21.1; also elsewhere on the board
USEL10#2: IC5.1 (IN); also elsewhere on the board
USEL100#2: IC5.16 (IN); also elsewhere on the board

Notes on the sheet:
Licensed under the TAPR Open Hardware License (www.tapr.org/OHL)
Repository: https://github.com/eez-open
More info at http://www.envox.hr/eez
AFE channel #2 (High voltage)

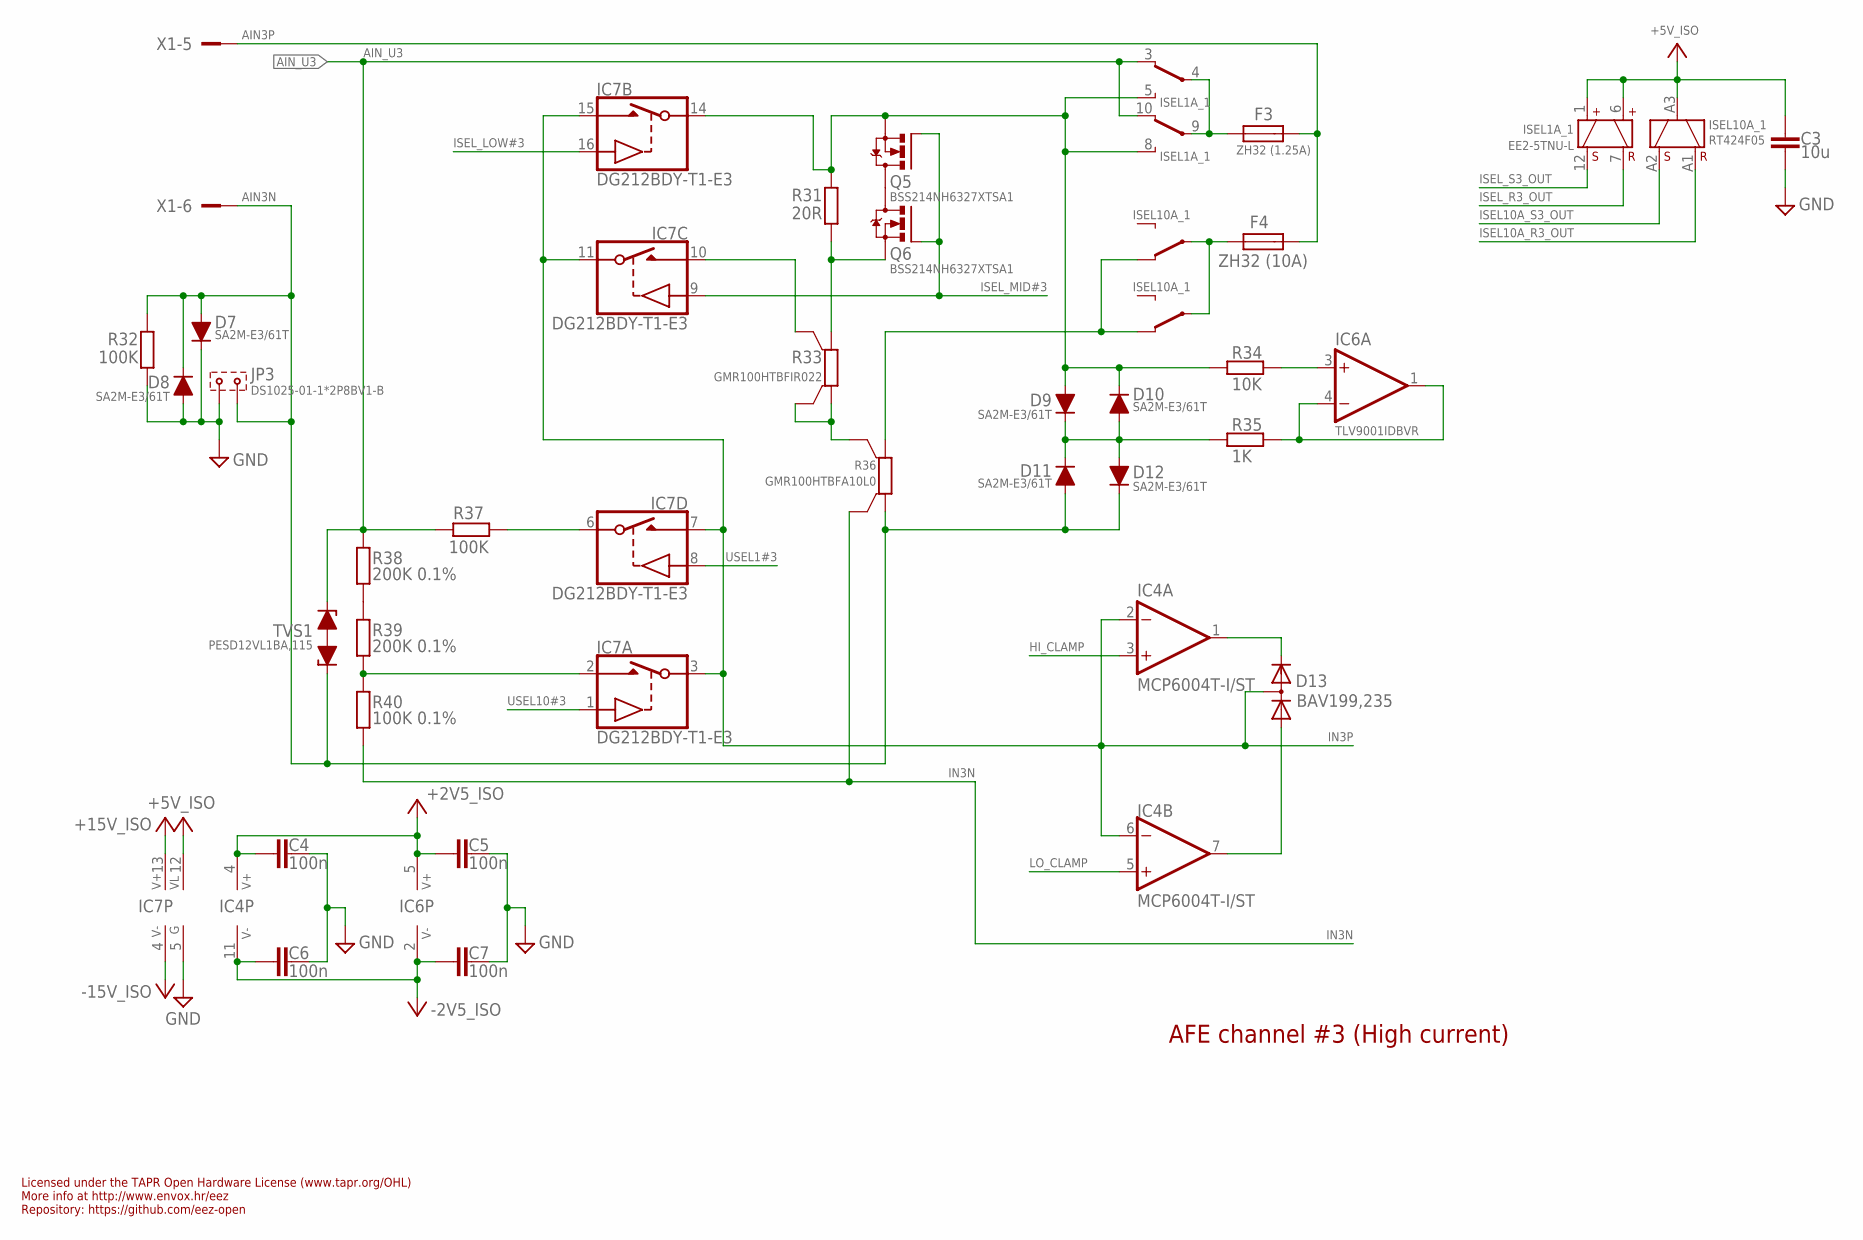
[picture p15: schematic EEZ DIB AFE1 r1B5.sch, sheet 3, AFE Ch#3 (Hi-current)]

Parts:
C3: 10u; C1206
C4, C5, C6, C7: 100n; C0603
D7, D8, D9, D10, D11, D12: SA2M-E3/61T; SMA_NARROW
D13: BAV199,235; SOT23
F3: ZH32 (1.25A); ZH32
F4: ZH32 (10A); ZH32
IC4: MCP6004T-I/ST; PW(R-PDSO-G14)
IC6: TLV9001IDBVR; DBV5
IC7: DG212BDY-T1-E3; SO16
ISEL1A_1: EE2-5TNU-L; G6SK-2F
ISEL10A_1: RT424F05; RT424FXX
JP3: DS1025-01-1*2P8BV1-B; 2MM-2
Q5: BSS214NH6327XTSA1; SOT103P240X110-3N; MPN 2N7002-7-F
Q6: BSS214NH6327XTSA1; SOT103P240X110-3N
R31: 20R; R1206
R32, R37: 100K; R1206
R33: GMR100HTBFIR022; R_2512-4WIRE
R34: 10K; R0805
R35: 1K; R0805
R36: GMR100HTBFA10L0; R_2512-4WIRE
R38, R39: 200K 0.1%; R1206
R40: 100K 0.1%; R1206
TVS1: PESD12VL1BA,115; SOD323-BIDIR
X1: 691322310008

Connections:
+2V5_ISO: C4.2, C5.2, IC4.4 (V+), IC6.5 (V+); also elsewhere on the board
+5V_ISO: C3.1, IC7.12 (VL), ISEL1A_1.1 (S+), ISEL1A_1.6 (R+), ISEL10A_1.A3 (COM); also elsewhere on the board
+15V_ISO: IC7.13 (V+); also elsewhere on the board
-2V5_ISO: C6.2, C7.2, IC4.11 (V-), IC6.2 (V-); also elsewhere on the board
-15V_ISO: IC7.4 (V-); also elsewhere on the board
AIN3N: D7.2 (A), D8.1 (C), D11.2 (A), D12.1 (C), JP3.1, R32.2, R36.1, TVS1.C1 (1), X1.6
AIN3P: F3.2, F4.2, X1.5
AIN3P_FUSED: F3.1, ISEL1A_1.4 (COM), ISEL1A_1.9 (COM)
AIN_U3: ISEL1A_1.3 (NC), ISEL1A_1.10 (NC), R37.2, R38.2, TVS1.C2 (2); also elsewhere on the board
GND: C3.2, C4.1, C5.1, C6.1, C7.1, D7.1 (C), D8.2 (A), IC7.5 (GND), JP3.2, R32.1; also elsewhere on the board
HI_CLAMP: IC4.3 (+IN); also elsewhere on the board
HI_CURR#2: ISEL10A_1.12 (NC), ISEL10A_1.22 (NC), R36.2
IN3N: R36.1S, R40.1; also elsewhere on the board
IN3P: D13.3 (AC), IC4.2 (-IN), IC4.6 (-IN), IC7.3 (S), IC7.7 (D), IC7.11 (S), IC7.15 (D); also elsewhere on the board
ISEL10A_R3_OUT: ISEL10A_1.A1 (R); also elsewhere on the board
ISEL10A_S3_OUT: ISEL10A_1.A2 (S); also elsewhere on the board
ISEL_LOW#3: IC7.16 (IN); also elsewhere on the board
ISEL_MID#3: IC7.9 (IN), Q5.1 (G), Q6.1 (G); also elsewhere on the board
ISEL_R3_OUT: ISEL1A_1.7 (R-); also elsewhere on the board
ISEL_S3_OUT: ISEL1A_1.12 (S-); also elsewhere on the board
LO_CLAMP: IC4.5 (+IN); also elsewhere on the board
unnamed: F4.1, ISEL10A_1.11 (COM), ISEL10A_1.21 (COM)
unnamed: R33.1, R33.1S, R36.2S
unnamed: Q6.2 (S), R31.1, R33.2
unnamed: Q5.3 (D), Q6.3 (D)
unnamed: IC7.10 (D), R33.2S
unnamed: D9.1 (C), D10.2 (A), D11.1 (C), D12.2 (A), R35.2
unnamed: D9.2 (A), D10.1 (C), IC7.14 (S), ISEL1A_1.5 (NO), ISEL1A_1.8 (NO), Q5.2 (S), R31.2, R34.2
unnamed: IC6.1 (OUT), IC6.4 (-IN), R35.1
unnamed: IC6.3 (+IN), R34.1
unnamed: R38.1, R39.2
unnamed: IC7.2 (D), R39.1, R40.2
unnamed: IC7.6 (S), R37.1
unnamed: D13.2 (C), IC4.1 (OUT)
unnamed: D13.1 (A), IC4.7 (OUT)
USEL1#3: IC7.8 (IN); also elsewhere on the board
USEL10#3: IC7.1 (IN); also elsewhere on the board

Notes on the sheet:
Licensed under the TAPR Open Hardware License (www.tapr.org/OHL)
Repository: https://github.com/eez-open
More info at http://www.envox.hr/eez
AFE channel #3 (High current)

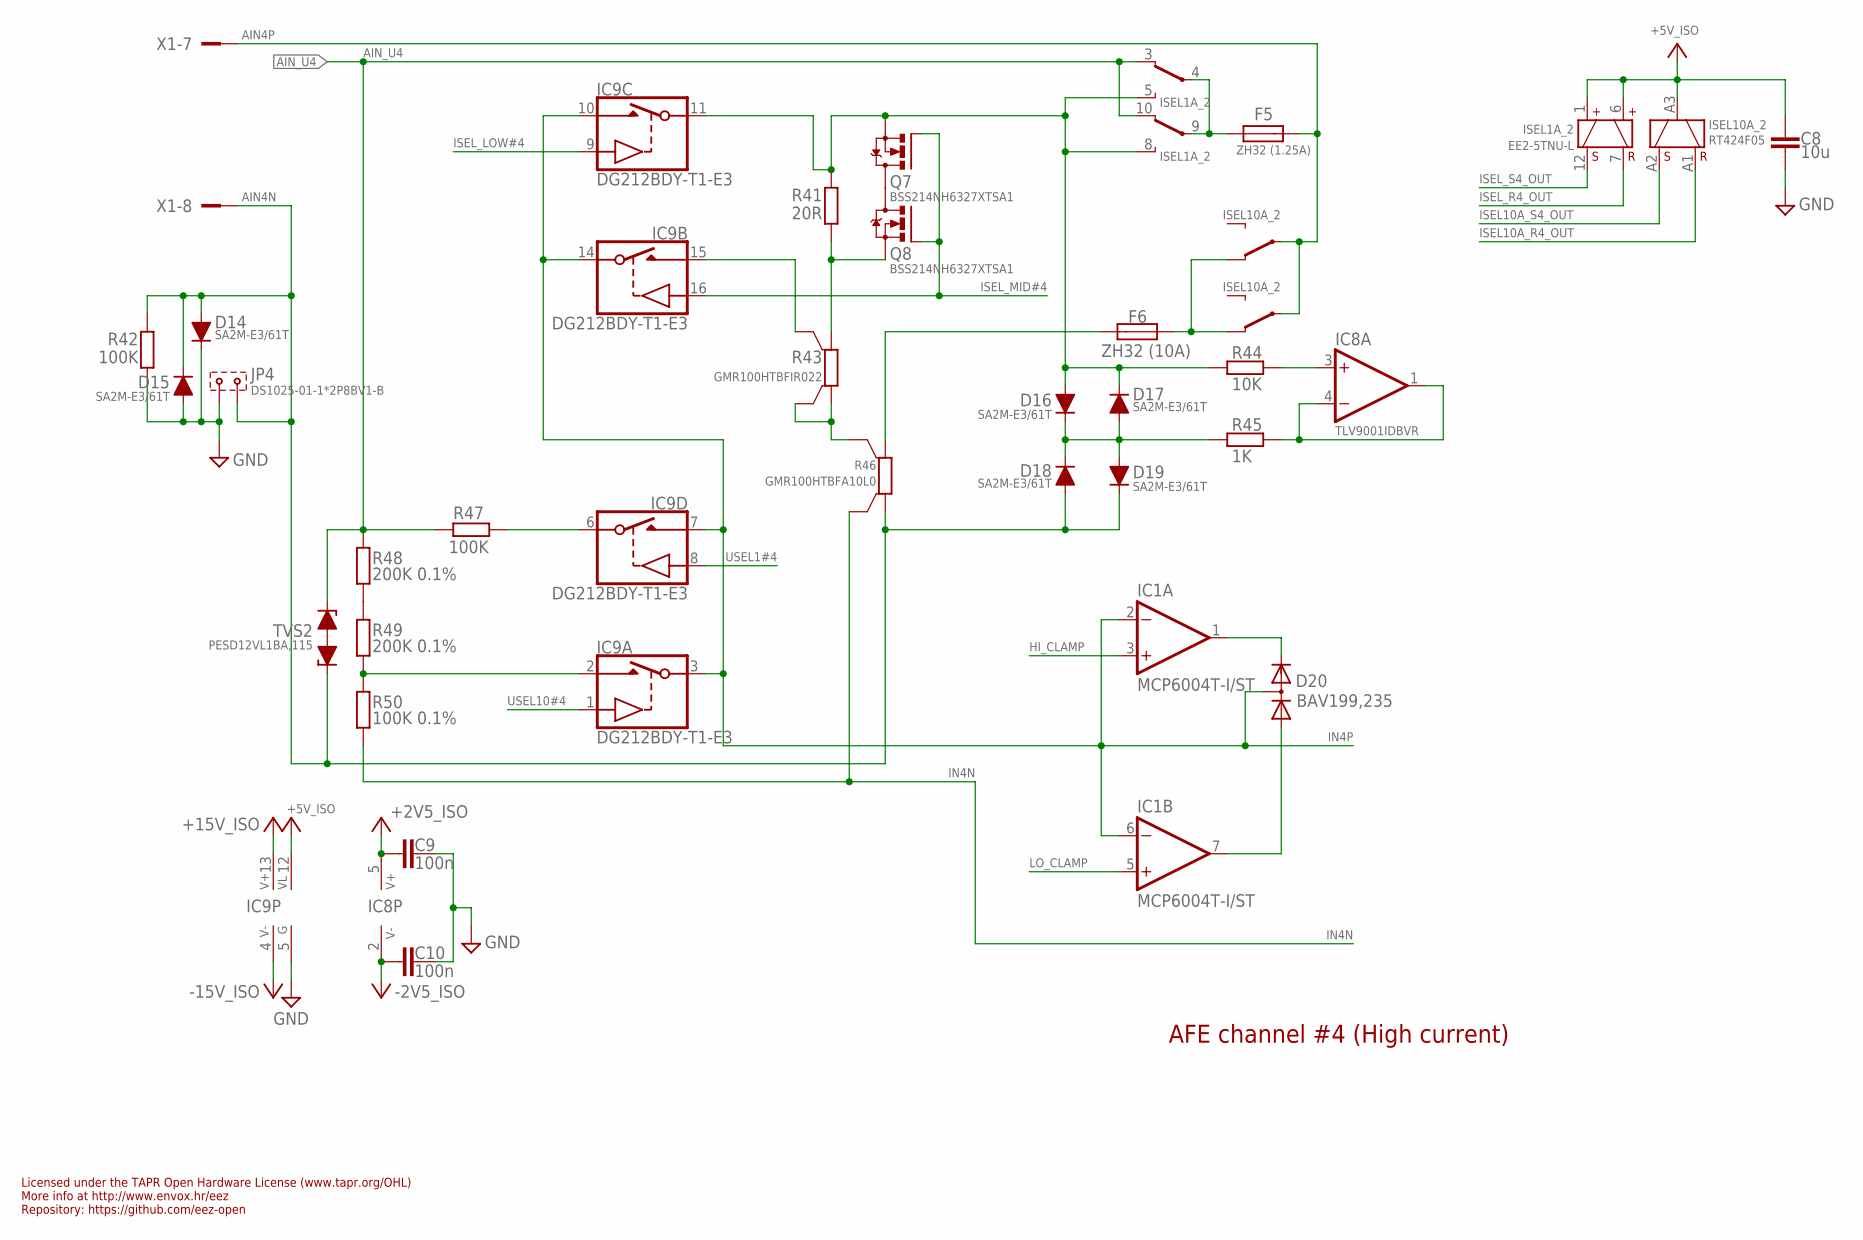
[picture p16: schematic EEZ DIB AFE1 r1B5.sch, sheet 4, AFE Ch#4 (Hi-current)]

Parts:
C8: 10u; C1206
C9, C10: 100n; C0603
D14, D15, D16, D17, D18, D19: SA2M-E3/61T; SMA_NARROW
D20: BAV199,235; SOT23
F5: ZH32 (1.25A); ZH32
F6: ZH32 (10A); ZH32
IC1: MCP6004T-I/ST; PW(R-PDSO-G14)
IC8: TLV9001IDBVR; DBV5
IC9: DG212BDY-T1-E3; SO16
ISEL1A_2: EE2-5TNU-L; G6SK-2F
ISEL10A_2: RT424F05; RT424FXX
JP4: DS1025-01-1*2P8BV1-B; 2MM-2
Q7: BSS214NH6327XTSA1; SOT103P240X110-3N; MPN 2N7002-7-F
Q8: BSS214NH6327XTSA1; SOT103P240X110-3N
R41: 20R; R1206
R42, R47: 100K; R1206
R43: GMR100HTBFIR022; R_2512-4WIRE
R44: 10K; R0805
R45: 1K; R0805
R46: GMR100HTBFA10L0; R_2512-4WIRE
R48, R49: 200K 0.1%; R1206
R50: 100K 0.1%; R1206
TVS2: PESD12VL1BA,115; SOD323-BIDIR
X1: 691322310008

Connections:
+2V5_ISO: C9.2, IC8.5 (V+); also elsewhere on the board
+5V_ISO: C8.1, IC9.12 (VL), ISEL1A_2.1 (S+), ISEL1A_2.6 (R+), ISEL10A_2.A3 (COM); also elsewhere on the board
+15V_ISO: IC9.13 (V+); also elsewhere on the board
-2V5_ISO: C10.2, IC8.2 (V-); also elsewhere on the board
-15V_ISO: IC9.4 (V-); also elsewhere on the board
AIN4N: D14.2 (A), D15.1 (C), D18.2 (A), D19.1 (C), JP4.1, R42.2, R46.1, TVS2.C1 (1), X1.8
AIN4P: F5.2, ISEL10A_2.11 (COM), ISEL10A_2.21 (COM), X1.7
AIN4P_FUSED: F5.1, ISEL1A_2.4 (COM), ISEL1A_2.9 (COM)
AIN_U4: ISEL1A_2.3 (NC), ISEL1A_2.10 (NC), R47.2, R48.2, TVS2.C2 (2); also elsewhere on the board
GND: C8.2, C9.1, C10.1, D14.1 (C), D15.2 (A), IC9.5 (GND), JP4.2, R42.1; also elsewhere on the board
HI_CLAMP: IC1.3 (+IN); also elsewhere on the board
HI_CURR#4: F6.2, R46.2
IN4N: R46.1S, R50.1; also elsewhere on the board
IN4P: D20.3 (AC), IC1.2 (-IN), IC1.6 (-IN), IC9.3 (S), IC9.7 (D), IC9.10 (D), IC9.14 (S); also elsewhere on the board
ISEL10A_R4_OUT: ISEL10A_2.A1 (R); also elsewhere on the board
ISEL10A_S4_OUT: ISEL10A_2.A2 (S); also elsewhere on the board
ISEL_LOW#4: IC9.9 (IN); also elsewhere on the board
ISEL_MID#4: IC9.16 (IN), Q7.1 (G), Q8.1 (G); also elsewhere on the board
ISEL_R4_OUT: ISEL1A_2.7 (R-); also elsewhere on the board
ISEL_S4_OUT: ISEL1A_2.12 (S-); also elsewhere on the board
LO_CLAMP: IC1.5 (+IN); also elsewhere on the board
unnamed: F6.1, ISEL10A_2.12 (NC), ISEL10A_2.22 (NC)
unnamed: Q8.2 (S), R41.1, R43.2
unnamed: D16.1 (C), D17.2 (A), D18.1 (C), D19.2 (A), R45.2
unnamed: D16.2 (A), D17.1 (C), IC9.11 (S), ISEL1A_2.5 (NO), ISEL1A_2.8 (NO), Q7.2 (S), R41.2, R44.2
unnamed: IC8.1 (OUT), IC8.4 (-IN), R45.1
unnamed: IC8.3 (+IN), R44.1
unnamed: R48.1, R49.2
unnamed: IC9.2 (D), R49.1, R50.2
unnamed: IC9.6 (S), R47.1
unnamed: D20.2 (C), IC1.1 (OUT)
unnamed: D20.1 (A), IC1.7 (OUT)
unnamed: IC9.15 (D), R43.2S
unnamed: Q7.3 (D), Q8.3 (D)
unnamed: R43.1, R43.1S, R46.2S
USEL1#4: IC9.8 (IN); also elsewhere on the board
USEL10#4: IC9.1 (IN); also elsewhere on the board

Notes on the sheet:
Licensed under the TAPR Open Hardware License (www.tapr.org/OHL)
Repository: https://github.com/eez-open
More info at http://www.envox.hr/eez
AFE channel #4 (High current)

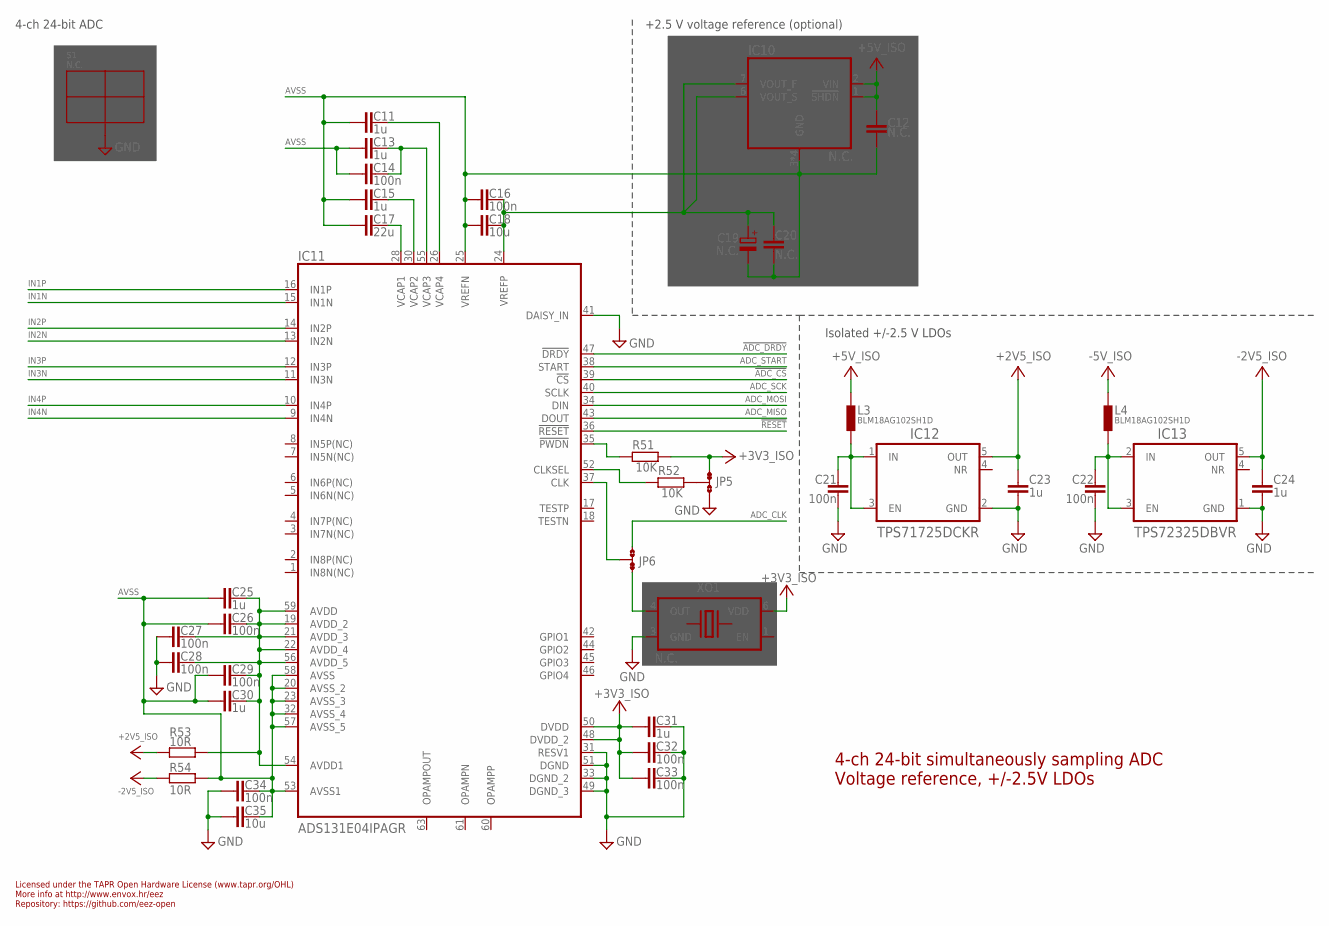
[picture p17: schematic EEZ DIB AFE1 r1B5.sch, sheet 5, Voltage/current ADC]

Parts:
C11, C13, C15, C23, C24, C25, C30, C31: 1u; C0805
C12: N.C.; C1206
C14, C16, C21, C22, C26, C27, C28, C29, C32, C33, C34: 100n; C0603
C17: 22u; C1206
C18, C35: 10u; C1206
C19: N.C.; EC1206
C20: N.C.; C050-075X110
IC10: N.C.; MSOP-8_MS_LIT
IC11: ADS131E04IPAGR; PAG64
IC12: TPS71725DCKR; DCK5
IC13: TPS72325DBVR; DBV5
JP5, JP6: JP3-CUT-0805-ROTATED; JP3-0805-CUT2
L3, L4: BLM18AG102SH1D; BEAD0603
R51, R52: 10K; R0805
R53, R54: 10R; R0805
S1: N.C.; 2118732-2
XO1: N.C.; XLH

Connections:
!ADC_CS: IC11.39 (!CS); also elsewhere on the board
!ADC_DRDY: IC11.47 (!DRDY); also elsewhere on the board
!RESET: IC11.36 (!RESET); also elsewhere on the board
+2V5_ADC: C25.2, C26.1, C27.1, C28.1, C29.1, C30.2, IC11.19 (AVDD_2), IC11.21 (AVDD_3), IC11.22 (AVDD_4), IC11.54 (AVDD1), IC11.56 (AVDD_5), IC11.59 (AVDD), R53.2
+2V5_ISO: C23.2, IC12.5 (OUT), R53.1; also elsewhere on the board
+3V3_ISO: C31.1, C32.2, C33.2, IC11.48 (DVDD_2), IC11.50 (DVDD), JP5.NC, R51.2, XO1.6 (VDD); also elsewhere on the board
+5V_ISO: C12.1, IC10.1 (!SHDN), IC10.2 (VIN), L3.P$2 (2); also elsewhere on the board
-2V5_ISO: C24.2, IC13.5 (OUT), R54.2; also elsewhere on the board
-5V_ISO: L4.P$2 (2); also elsewhere on the board
ADC_CLK: JP6.NO; also elsewhere on the board
ADC_MISO: IC11.43 (DOUT); also elsewhere on the board
ADC_MOSI: IC11.34 (DIN); also elsewhere on the board
ADC_SCK: IC11.40 (SCLK); also elsewhere on the board
ADC_START: IC11.38 (START); also elsewhere on the board
AVSS: C11.1, C12.2, C13.1, C14.2, C15.1, C16.2, C17.1, C18.2, C19.-, C20.2, C25.1, C26.2, C29.2, C30.1, C34.1, C35.1, IC10.3 (GND), IC10.4 (GND), IC10.5 (GND), IC10.8 (GND), IC11.20 (AVSS_2), IC11.23 (AVSS_3), IC11.25 (VREFN), IC11.32 (AVSS_4), IC11.53 (AVSS1), IC11.57 (AVSS_5), IC11.58 (AVSS), R54.1
GND: C21.2, C22.2, C23.1, C24.1, C27.2, C28.2, C31.2, C32.1, C33.1, C34.2, C35.2, IC11.31 (RESV1), IC11.33 (DGND_2), IC11.41 (DAISY_IN), IC11.49 (DGND_3), IC11.51 (DGND), IC12.2 (GND), IC13.1 (GND), JP5.NO, S1.SH.1, S1.SH.2, S1.SH.3, S1.SH.4, S1.SH.5, S1.SH.6, S1.SH.7, S1.SH.8, XO1.3 (GND); also elsewhere on the board
IN1N: IC11.15 (IN1N); also elsewhere on the board
IN1P: IC11.16 (IN1P); also elsewhere on the board
IN2N: IC11.13 (IN2N); also elsewhere on the board
IN2P: IC11.14 (IN2P); also elsewhere on the board
IN3N: IC11.11 (IN3N); also elsewhere on the board
IN3P: IC11.12 (IN3P); also elsewhere on the board
IN4N: IC11.9 (IN4N); also elsewhere on the board
IN4P: IC11.10 (IN4P); also elsewhere on the board
unnamed: IC11.52 (CLKSEL), R52.1
unnamed: C21.1, IC12.1 (IN), IC12.3 (EN), L3.P$1 (1)
unnamed: C22.1, IC13.2 (IN), IC13.3 (EN), L4.P$1 (1)
unnamed: JP5.COM, R52.2
unnamed: C17.2, IC11.28 (VCAP1)
unnamed: C15.2, IC11.30 (VCAP2)
unnamed: C13.2, C14.1, IC11.55 (VCAP3)
unnamed: C11.2, IC11.26 (VCAP4)
unnamed: IC11.37 (CLK), JP6.COM
unnamed: JP6.NC, XO1.4 (OUT)
unnamed: IC11.35 (!PWDN), R51.1
VREFP: C16.1, C18.1, C19.+, C20.1, IC10.6 (VOUT_S), IC10.7 (VOUT_F), IC11.24 (VREFP)

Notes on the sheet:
Licensed under the TAPR Open Hardware License (www.tapr.org/OHL)
Repository: https://github.com/eez-open
More info at http://www.envox.hr/eez
4-ch 24-bit simultaneously sampling ADC Voltage reference, +/-2.5V LDOs
4-ch 24-bit ADC
+2.5 V voltage reference (optional)
Isolated +/-2.5 V LDOs

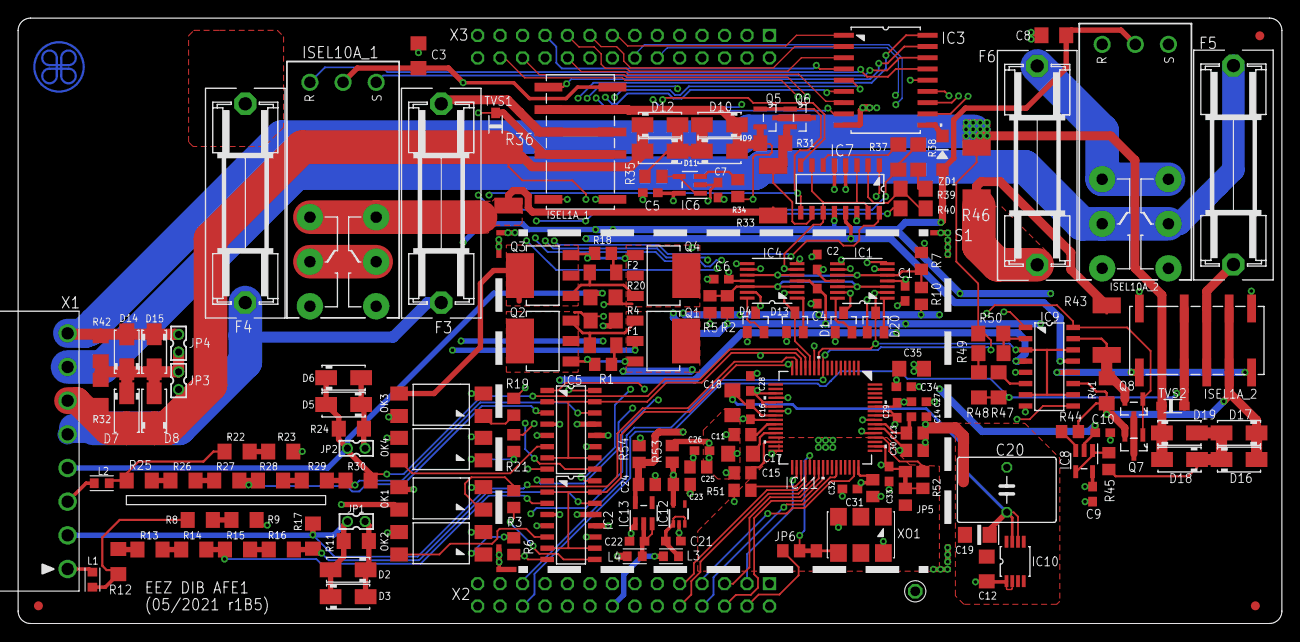
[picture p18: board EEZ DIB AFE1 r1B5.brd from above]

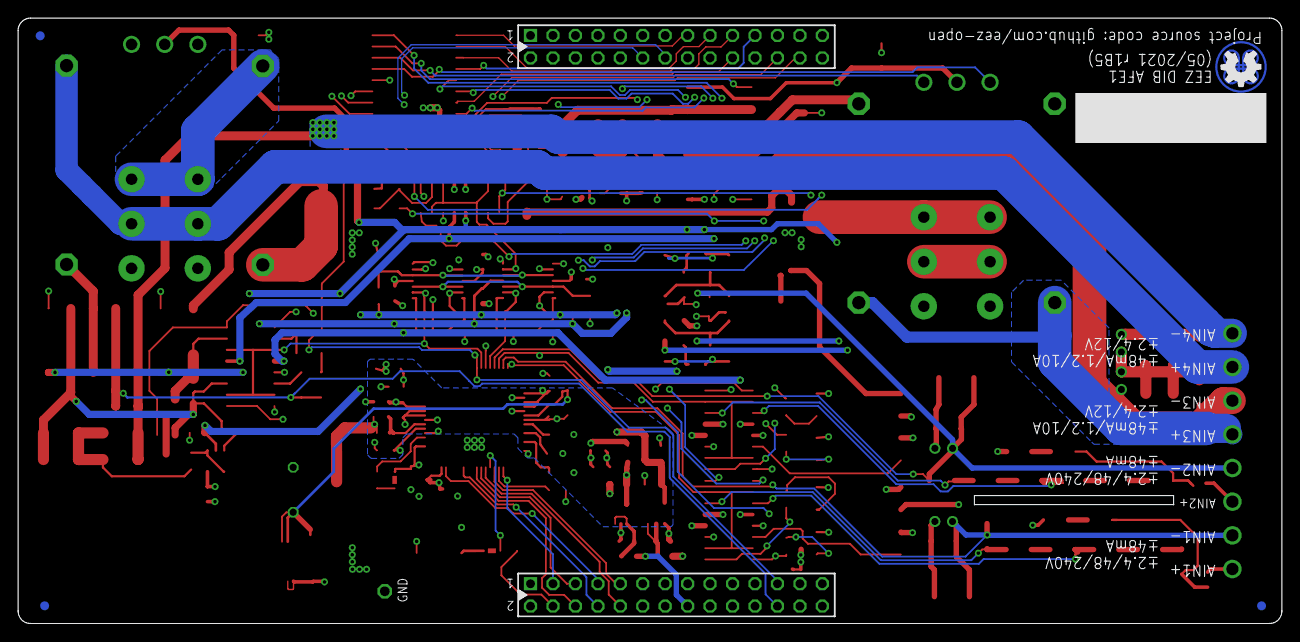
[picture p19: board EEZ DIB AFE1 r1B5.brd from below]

Board: 4 copper layers, 143.0 x 68.5 mm, 167 parts (2 on the bottom side), 149 nets.

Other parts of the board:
EEZ_SIGNATURE: SIGNATURESMALL; SIGNATURE_5MM

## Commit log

2021-01-23 small PCB layout changes
    [EEZ DIB AFE1 r1B3.brd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]
2021-01-24 PCB silkscreen fix
    [EEZ DIB AFE1 r1B3.brd, EEZ DIB AFE1 r1B3.sch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]
2021-01-27 active clamp op-amps changed
    [EEZ DIB AFE1 r1B3.brd, EEZ DIB AFE1 r1B3.sch]
2021-05-09 #1, #2, BOM (r1B5)
    [EEZ DIB AFE1 r1B5 BOM.ods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]
2021-05-14 New Rsense values, PCB layout adjustment for mid range Rsense
    [EEZ DIB AFE1 r1B5 BOM.ods, EEZ DIB AFE1 r1B5.brd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]
2021-05-14 BOM update
    [EEZ DIB AFE1 r1B5 BOM.ods]

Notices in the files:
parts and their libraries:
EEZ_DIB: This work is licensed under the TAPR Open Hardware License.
